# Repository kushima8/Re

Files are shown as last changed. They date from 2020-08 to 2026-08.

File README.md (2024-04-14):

# Re
Split keyboards with rotary encoder<br>

Re40＆Re64

# Build Guide

## Re42_Rev2
End of distribution<br>
[ビルドガイド（日本語）](Re42/Documents/rev2_buildguide_v1.0.md)  
[PCB](https://github.com/kushima8/Re/tree/master/Re42/PCB)
## Re64_Rev2
End of distribution<br>
[ビルドガイド（日本語）](Re64/Documents/rev2_buildguide_v1.0.md)  
[PCB](https://github.com/kushima8/Re/tree/master/Re64/PCB)
## Re93
End of distribution<br>
[ビルドガイド（日本語）](Re93/Documents/buildguide_v1.0.md)  
[PCB](https://github.com/kushima8/Re/tree/master/Re93/PCB)
## Re40
End of distribution<br>
[ビルドガイド（日本語）](Re40/Documents/buildguide_v1.0.md)
## Re42
End of distribution<br>
[ビルドガイド（日本語）](Re42/Documents/buildguide_v1.0.md)
## Re64
End of distribution<br>
[ビルドガイド（日本語）](Re64/Documents/buildguide_v1.0.md)

120px-Cc-by-nc-sa_icon svg

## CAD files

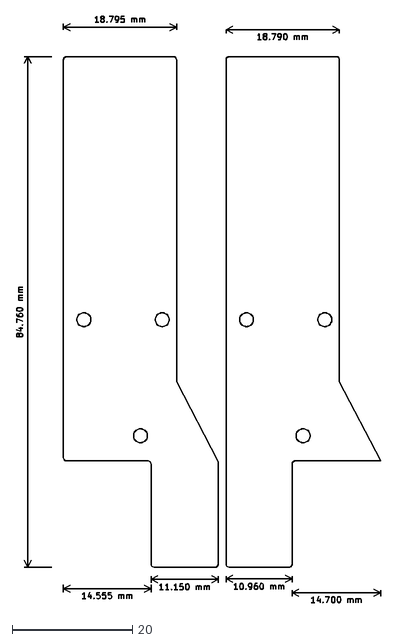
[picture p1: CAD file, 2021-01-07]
Re40/Plate/re40_protective.dxf
60.5 x 97.3

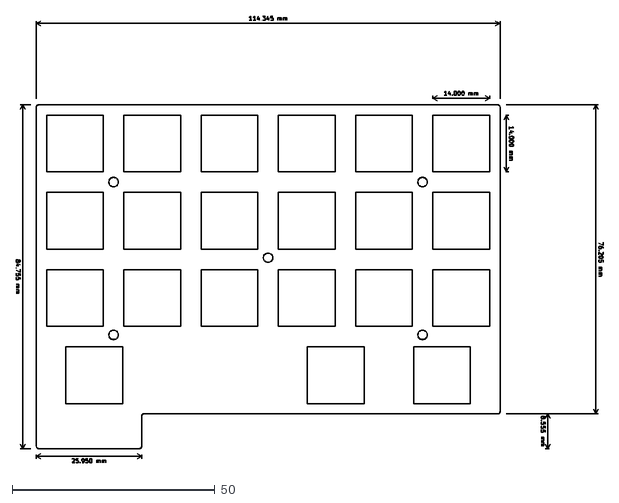
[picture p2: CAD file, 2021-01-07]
Re42/Plate/re42_top.dxf
144.8 x 110.1

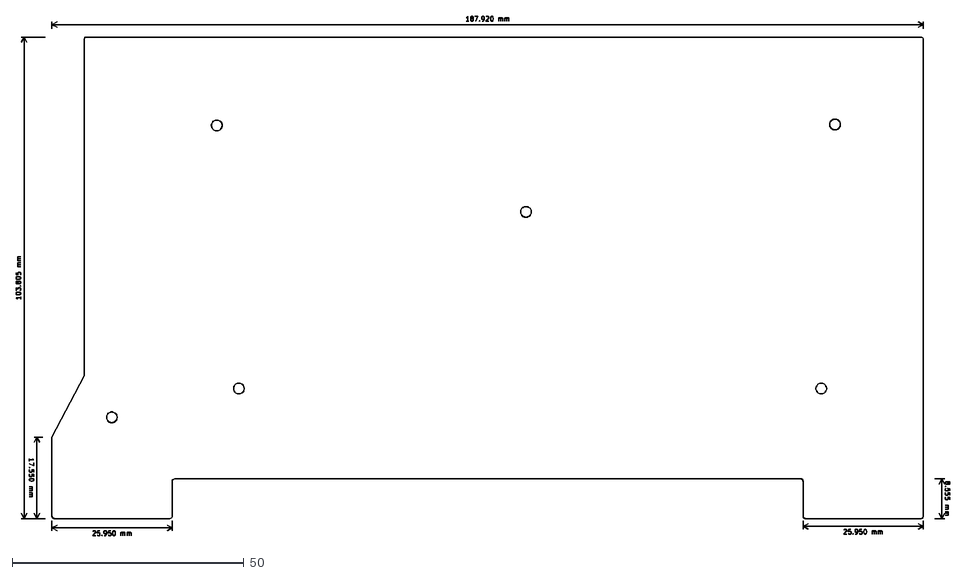
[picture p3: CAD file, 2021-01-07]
Re64/Plate/re64r_bottom.dxf
201.4 x 112.0

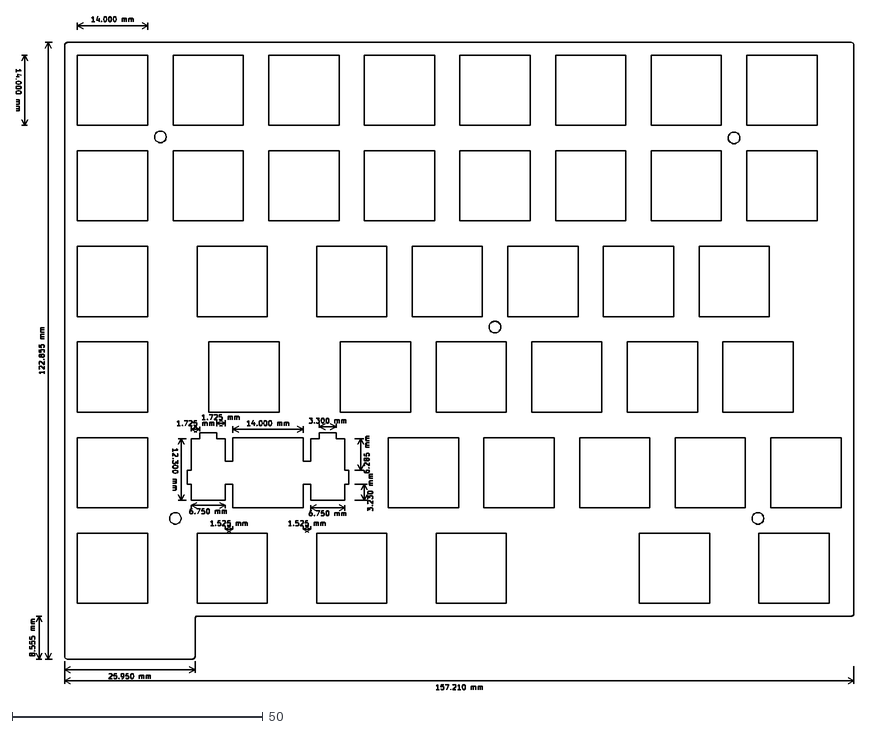
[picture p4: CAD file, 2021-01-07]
Re93/Plate/re93l_top.dxf
166.9 x 134.1

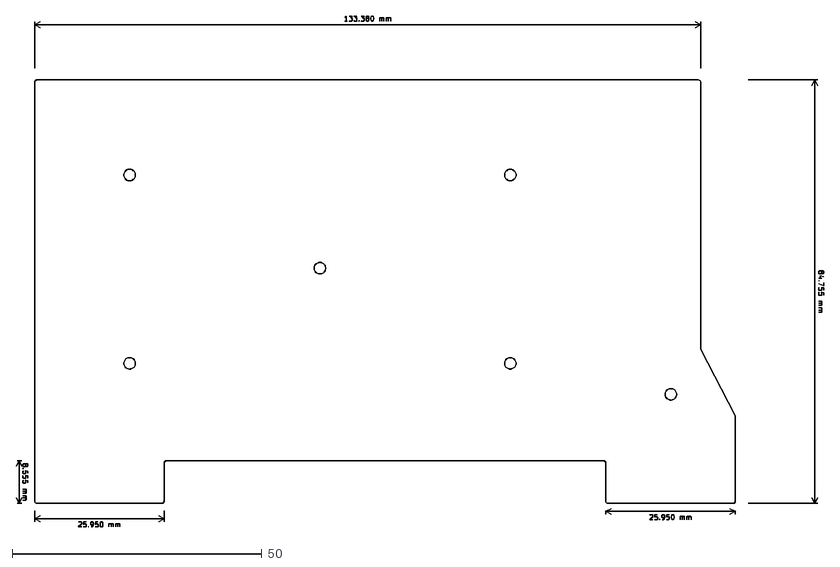
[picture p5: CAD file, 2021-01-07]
Re40/Plate/re40_bottom.dxf
161.7 x 102.3

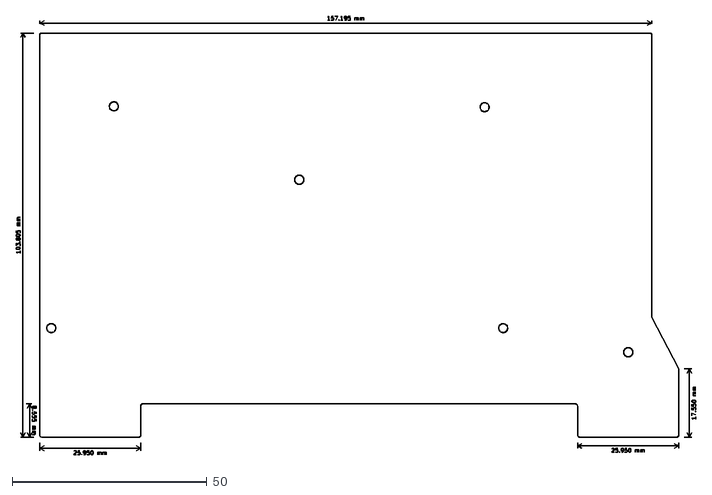
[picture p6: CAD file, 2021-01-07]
Re64/Plate/re64l_bottom.dxf
174.6 x 112.6

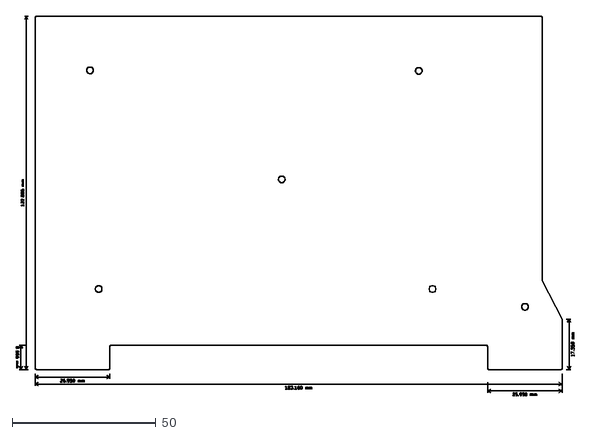
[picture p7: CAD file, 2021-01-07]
Re93/Plate/re93l_bottom.dxf
194.0 x 132.0

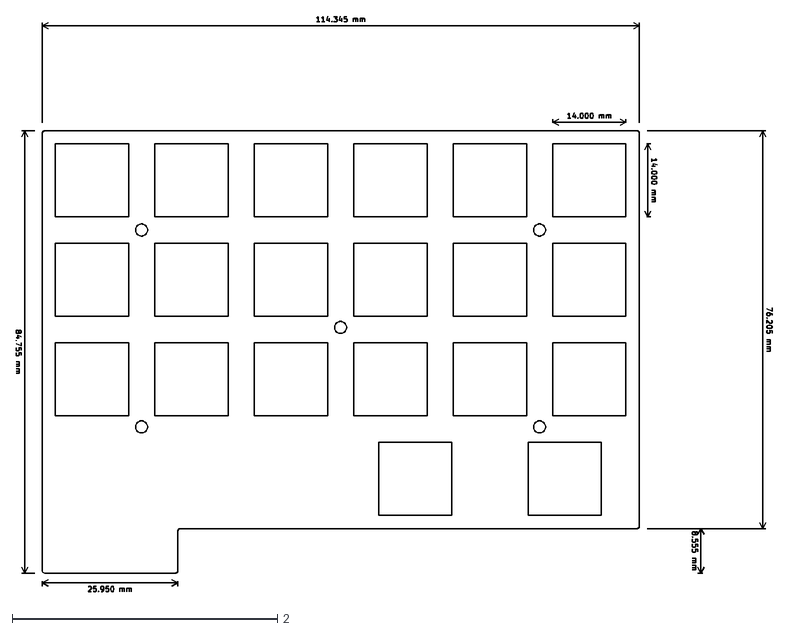
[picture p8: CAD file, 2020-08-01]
Re40/Plate/Re40_top.dxf
5.70 x 4.34

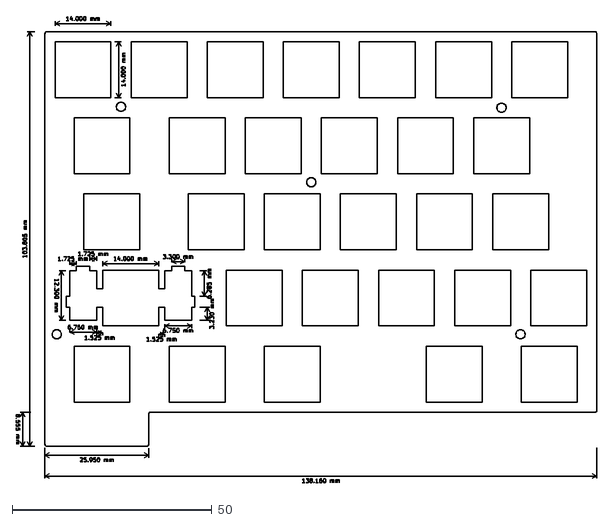
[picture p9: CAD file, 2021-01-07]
Re64/Plate/re64l_top.dxf
145.4 x 116.7

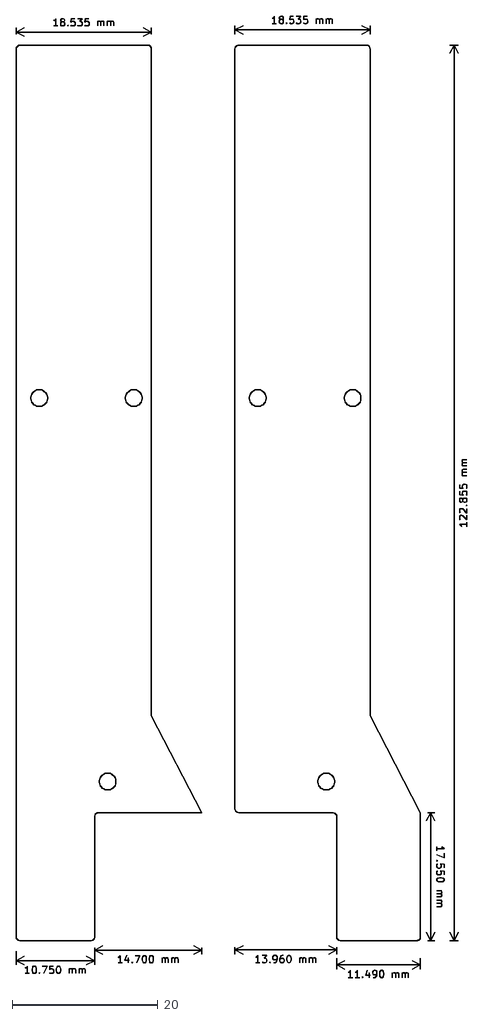
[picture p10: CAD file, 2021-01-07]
Re93/Plate/re93_protective.dxf
61.8 x 131.9

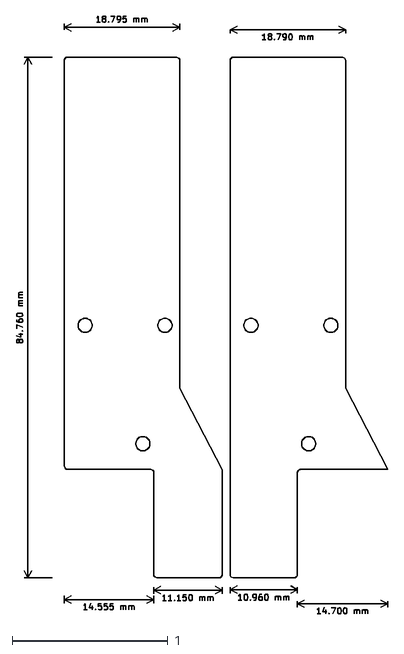
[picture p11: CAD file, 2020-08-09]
Re42/Plate/re42_protective.dxf.dxf
2.38 x 3.83

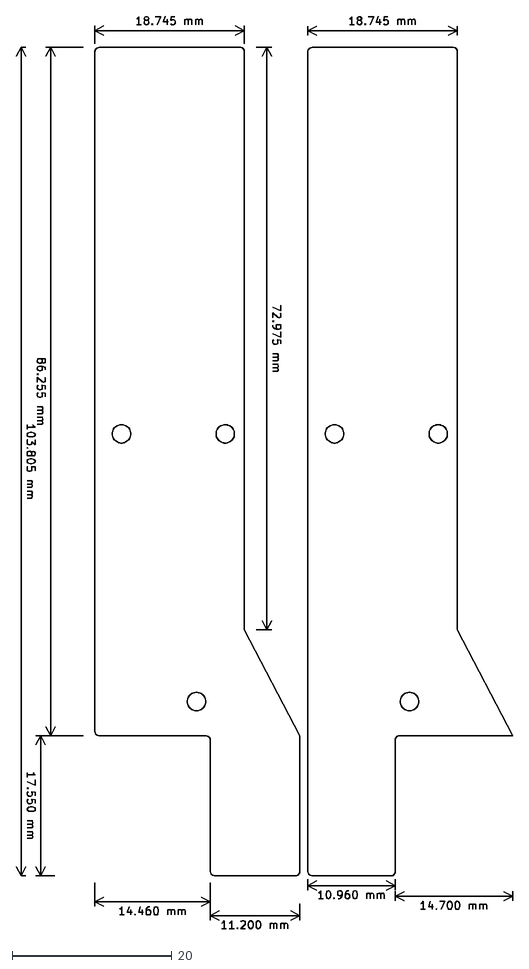
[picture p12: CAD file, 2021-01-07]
Re64/Plate/re64_protective.dxf
62.2 x 114.3

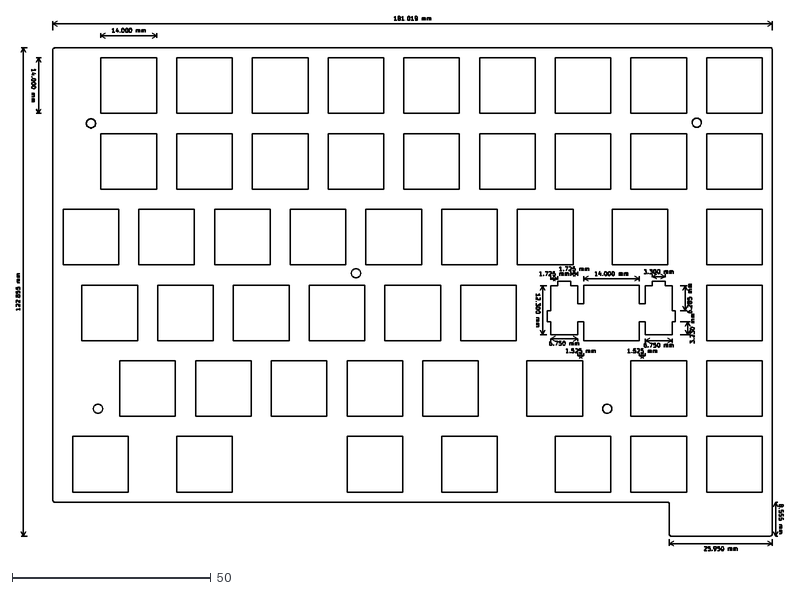
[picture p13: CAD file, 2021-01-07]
Re93/Plate/re93r_top.dxf
193.0 x 134.3

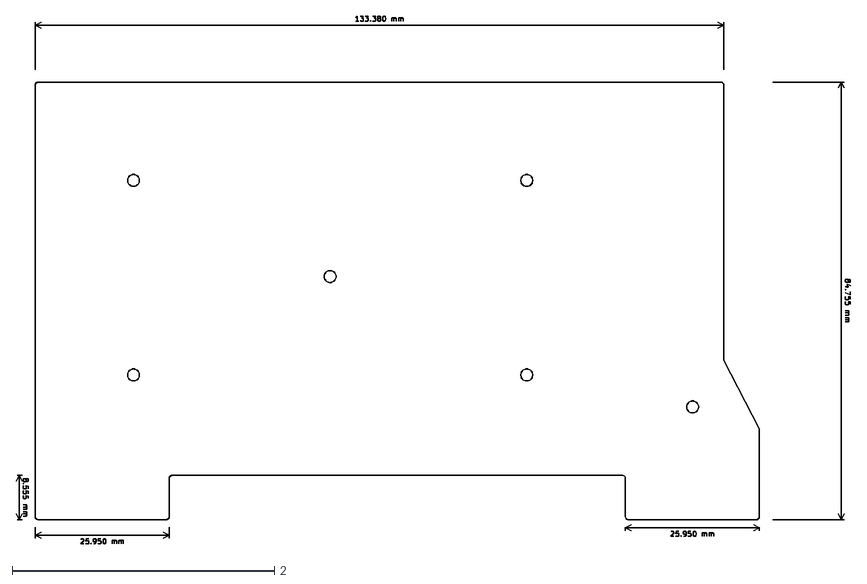
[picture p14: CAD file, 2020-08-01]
Re42/Plate/re42_bottm.dxf
6.37 x 4.03

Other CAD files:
Re64/Plate/re64r_top.dxf
Re93/Plate/re93r_bottom.dxf

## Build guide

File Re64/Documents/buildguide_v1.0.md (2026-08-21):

# Re64_Rev1.0 ビルドガイド

## ご購入前にお読みください

本製品をご購入いただいた時点で、下記「譲渡・再販について」の内容にご同意いただいたものとみなします。

### 譲渡・再販について

BOOTHや遊舎工房など、作者本人が販売または委託している場所以外で購入された場合、同梱品の不足や不良品への対応など、各種サポートをいたしかねます。  
そのため、以下のとおりお願いしております。

1. 本製品（完成品・未完成品・付属部品を問わず）を、ネットオークション、フリマサービス、その他の方法により第三者へ有償で譲渡することを禁止します。
2. 本項に反する行為を確認した場合、以後の販売をお断りする場合があります。

## はじめに
このたびはご購入いただきありがとうございます。  
本製品は組み立てが必要なキットです。  

Re64は親指で操作可能なロータリーエンコーダーを備え、プログラマーなどに人気の高いあの配列を踏襲した60％分割キーボードです。  
使用するキーキャップについては[キーレイアウト](http://www.keyboard-layout-editor.com/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'&_w:2.25%3B&=Enter%3B&@_w:2.25%3B&=Shift&=Z&=X&=C&=V&=B&_x:3.75%3B&=N&=M&=%3C%0A,&=%3E%0A.&=%3F%0A%2F%2F&_w:1.75%3B&=Shift&=Fn%3B&@_w:1.5%3B&=Ctrl&=Fn&_w:1.5%3B&=GUI&_x:0.75&w:1.25%3B&=Space&_w:1.25%3B&=Space&_x:3&w:1.25%3B&=Space&_w:1.5%3B&=Space&_x:0.75&w:1.5%3B&=GUI&=ALT%3B&@_y:-0.75&x:7.25%3B&=SECOND&_x:1%3B&=SECOND)を確認してください。  
※中央付近に突き出した1Uはロータリーエンコーダーのブッシュスイッチを表しています。  

写真は作成見本であり商品内容と同一ではありません。  
また仕様は予告なく変更されることがあります。  

ファームウェアに[qmk_firmware](https://github.com/qmk/qmk_firmware)を採用しています。  
QMKにRe64のコードはまだマージされていませんのでこの[ブランチ](https://github.com/kushima8/qmk_firmware/tree/re)を使用してください。  
動作確認の為にdefaultの[HEXファイル](https://github.com/kushima8/Re/blob/master/Re64/HEX)を用意しています。  
defaultを使用した場合、左側のPro MicroとPCを接続する設定となっております。  
右側で接続した場合はキーマップが反転します。  
反転せずに右側接続を行いたい場合は、右側最上段右端のキーを押下しながら接続することで対応可能です。  

キット作成前にPro Microの書き込み環境の構築を行ってください。  
ファームウェアの書き込み環境の構築については下記のサリチル酸さんのサイトを参考にしてください。  
[（初心者編）自作キーボードにファームウェアを書き込む](https://salicylic-acid3.hatenablog.com/entry/qmk-toolbox)  

キー割り当ての変更方法などはご自身でお調べいただくようお願いします。  

GUIから簡単にキー割り当てを変更できる[VIA](https://caniusevia.com/)と[Remap](https://remap-keys.app/)に対応しております。  
ロータリーエンコーダの回転割り当ても含め、設定できますのでご活用ください。  
VIAとRemapについては下記のサリチル酸さんのサイトを参考にしてください。  
[（初心者編）VIAを使ってキーマップを書き換えよう](https://salicylic-acid3.hatenablog.com/entry/via-manual)  
[（初心者編）Remapを使ってキーマップを書き換えよう](https://salicylic-acid3.hatenablog.com/entry/remap-manual)  
OLEDを接続していない場合は[re64_via.hex](https://github.com/kushima8/Re/blob/master/Re64/VIA/re64_via.hex)を、  
接続している場合は[re64_via_oled.hex](https://github.com/kushima8/Re/blob/master/Re64/VIA/re64_via_oled.hex)を使用してください。  
[re64_via.hex](https://github.com/kushima8/Re/blob/master/Re64/VIA/re64_via.hex)と[re64_via_oled.hex](https://github.com/kushima8/Re/blob/master/Re64/VIA/re64_via_oled.hex)ではロータリーエンコーダの初期割り当てが未設定ですので、動作確認時には[Remap](https://remap-keys.app/)などで割り当て設定をしてください。  

[プレートのデータ](https://github.com/kushima8/Re/tree/master/Re64/Plate)は公開中です。  
アルミプレートなど作成したい場合にお使いください。  

Type-C端子搭載のiPadと接続可能です。  
iPad mini 6にて簡易動作確認済みです。  
一部iPadでは対応していないキーコードがありますのでご注意ください。  

以下の部品リストを参考に欠品がないか確認をお願いします。  

## 部品

### キットに付属しているもの

|名称|数量|備考|
|----|:---:|----|
|PCB|2枚|右側用、左側用各1枚ずつ|
|トッププレート|2枚|右側用、左側用各1枚ずつ|
|ボトムプレート|2枚|右側用、左側用各1枚ずつ|
|保護プレート|4枚|内側用、外側用各2枚ずつ|
|M2 3mmスペーサー(ARB-2003E)|10個|丸型両メネジ|
|M2 6mmスペーサー(ARB-2006E)|12個|丸型両メネジ|
|M2 8mmスペーサー(ARB-2008E)|6個|丸型両メネジ|
|M2 4mmネジ|20本|
|M2 8mmネジ|10本|
|M2 12mmネジ|2本|
|ダイオード(1N4148)|66本|若干多めの場合あり|
|Kailh PCB ソケット(MX用)|64個|
|タクトスイッチ|2個|
|TRRSジャック(MJ-4PP-9)|2個|
|プッシュスイッチ内蔵ロータリーエンコーダ(PEC12R-4222F-S0024)|2個|
|ゴム足|8個|

### 別途、購入が必ず必要なもの
以下の部品は別途購入してください。

|名称|数量|備考|
|----|:---:|----|
|キースイッチ(Cherry MX互換)|64個|
|キーキャップ(Cherry MX互換)|64個|
|Pro Micro|2個|
|コンスルーピンヘッダ	|4個|
|ロータリーエンコーダー用つまみ|2個|
|TRRSケーブル|1本|
|2Uスタビライザー(Cherry MX互換)|2個|

### オプション
以下の部品はオプション品です。
キーボードを光らせたいなどの場合のみ別途購入してください。

|名称|数量|備考|
|----|:---:|----|
|LEDチップ(YS-SK6812MINI-E)|64個|
|OLEDモジュール|2個|
|OLED用ピンソケット|2個|

## 組み立て
* Daihukuさんによるビルドログ動画があります。  
  本機を作成するにあたって参考になると思いますので是非御覧ください。  
 https://www.youtube.com/watch?v=lg03LpNXRAI
* 表面  
  
* 裏面  
  
* 1.Pro Microのはんだ付け
  * チップが載っている面が内側になるようにし、コンスルーピンヘッダを取り付けはんだ付けをしてください。
  * コンスルーピンヘッダには取り付け方向があるため気をつけてください。
  * [コンスルー - Self-Made Keyboards in Japan - ](https://scrapbox.io/self-made-kbds-ja/%E3%82%B3%E3%83%B3%E3%82%B9%E3%83%AB%E3%83%BC)  
  
* 2.ファームウェアの書き込み
  * [re64_default.hex](https://github.com/kushima8/Re/blob/master/Re64/HEX/re64_default.hex)を指定してファームウェアを書き込んでください。
  * OLEDを使用する場合は'rules.mk'内の'OLED_DRIVER_ENABLE'を'yes'に書き換え、ご自身で環境を作っていただきファームウェアをコンパイルして頂くか、
  * もしくは[re64_via_oled.hex](https://github.com/kushima8/Re/blob/master/Re64/VIA/re64_via_oled.hex)を指定してファームウェアを書き込んでください。
  * [re64_via_oled.hex](https://github.com/kushima8/Re/blob/master/Re64/VIA/re64_via_oled.hex)ではロータリーエンコーダの初期割り当てが未設定ですので、動作確認時には[Remap](https://remap-keys.app/)などで割り当て設定をしてください。
* 3.LEDチップのはんだ付け(オプション)
  * LEDチップ((YS-SK6812MINI-E)はPCBを裏面にして右上から左下、反転したZ字を書くように実装してください。
  * 高い温度ではんだ付けを行うとLED破損の可能性がありますので、約270℃に設定してはんだ付けをするようにしてください。
  * LEDは足が欠けている箇所が左下に来るように設置し、はんだ付けを行ってください。
  * はんだ付けが完了したら一度Pro Microを取り付け、LEDが光るかどうかテストを行ってください。  
  
* 4.ダイオードのはんだ付け
  * ダイオードの足を曲げ、PCB前面から取り付け、裏面からはんだ付けを行ってください。
  * ダイオードの向きは前面から見て左(三角形の頂点の先に縦棒がある方)に黒帯が来るように設置しはんだ付けを行ってください。
* 5.Kailh PCB ソケット
  * 中央の穴に干渉しないようにソケットを設置してください。
  * ソケットの片側はんだ付けをしっかりと行い、基盤から浮いていないようであればもう片方もはんだ付けをしっかりと行ってください。
* 6.タクトスイッチ、TRRSジャックのはんだ付け
  * PCB表面から取り付け、裏面からはんだ付けを行ってください。
* 7.OLEDモジュール、OLED用ピンソケットのはんだ付け(オプション)
  * OLEDモジュールとピンヘッダのハンダ付けを行ってください。
  * ピンソケットをPCB表面から取り付け、裏面からはんだ付けを行ってください。
* 8.ロータリーエンコーダのはんだ付け
  * ロータリーエンコーダーの取り付け位置は内側と外側の選択式となっております。
  * どちらを選択しても同じ動作をするように設計しています。
  
  * 使用するつまみ、または自身の手の大きさなどを考慮し自身で内側か外側かの選択を行ってください。
  * 取り付け位置選択後、PCB表面からロータリーエンコーダを取り付け、裏面からはんだ付けを行ってください。
* 9.スタビライザーの取り付け
  * 基盤にスタビライザーを取り付けてください。
* 10.トッププレートの取り付け
  * トッププレートの保護フィルムを剥がし、M2 3mmスペーサーをM2 8mmネジで固定してください。
  * その後、PCB表面に取り付け、サンドするようにM2 6mmスペーサーを裏面から取り付けてください。
* 11.保護プレート用スペーサーの取り付け
  * Pro Micro取り付け位置直下に位置する2箇所の穴に裏面からM2 4mmネジを入れ、M2 8mmスペーサーで固定してください。
* 12.ボトムプレートの取り付け
  * ボトムプレートの保護フィルムを剥がし、基板上でロータリーエンコーダの上部に位置する穴に対して裏面からM2 12mmネジを入れ、M2 6mmスペーサーで固定してください。
  * その後、M2 4mmネジを仕様し残りの箇所を固定してください。
* 13.キースイッチの取り付け
  * 基盤にキースイッチを取り付けてください。
* 14.Pro Microの取り付け
  * Pro Microを取り付け、PCと接続し、キースイッチとロータリーエンコーダの入力の確認を行ってください。
* 15.OLEDモジュールの取り付け(オプション)
  * OLEDモジュールを取り付け、PCと接続し、表示されることの確認を行ってください。
  * デフォルトでは左側にはレイヤーとLEDの光度情報、右側は真っ白な長方形が表示されます。
* 16.保護プレートの取り付け
  * ロータリーエンコーダーを内側に取り付けた場合は外側用の、内側に取り付けた場合は外側用の保護プレートを使用します。
  * ロータリーエンコーダー上部に位置する箇所から飛び出ているネジにM2 8mmスペーサーを固定。
  * そして、保護フィルムを剥がし、表面からM2 4mmねじで保護プレートを固定してください。
* 17.つまみの取り付け
  * つまみをロータリーエンコーダーに取り付けてください。
* 18.キーキャップの取り付け
  * キースイッチにキーキャップを取り付けてください。
  * 使用するキーキャップについては[キーレイアウト](http://www.keyboard-layout-editor.com/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'&_w:2.25%3B&=Enter%3B&@_w:2.25%3B&=Shift&=Z&=X&=C&=V&=B&_x:3.75%3B&=N&=M&=%3C%0A,&=%3E%0A.&=%3F%0A%2F%2F&_w:1.75%3B&=Shift&=Fn%3B&@_w:1.5%3B&=Ctrl&=Fn&_w:1.5%3B&=GUI&_x:0.75&w:1.25%3B&=Space&_w:1.25%3B&=Space&_x:3&w:1.25%3B&=Space&_w:1.5%3B&=Space&_x:0.75&w:1.5%3B&=GUI&=ALT%3B&@_y:-0.75&x:7.25%3B&=SECOND&_x:1%3B&=SECOND)を確認してください。
* 19.ゴム足の取り付け
  * ボトムプレートにゴム足を取り付けください。

組み立ての手順は、以上です。

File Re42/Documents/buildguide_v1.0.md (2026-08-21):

# Re42_Rev1.0 ビルドガイド

## ご購入前にお読みください

本製品をご購入いただいた時点で、下記「譲渡・再販について」の内容にご同意いただいたものとみなします。

### 譲渡・再販について

BOOTHや遊舎工房など、作者本人が販売または委託している場所以外で購入された場合、同梱品の不足や不良品への対応など、各種サポートをいたしかねます。  
そのため、以下のとおりお願いしております。

1. 本製品（完成品・未完成品・付属部品を問わず）を、ネットオークション、フリマサービス、その他の方法により第三者へ有償で譲渡することを禁止します。
2. 本項に反する行為を確認した場合、以後の販売をお断りする場合があります。

## はじめに
このたびはご購入いただきありがとうございます。  
本製品は組み立てが必要なキットです。  

Re42は親指で操作可能なロータリーエンコーダーを備える40％分割キーボードです。  
使用するキーキャップについては[キーレイアウト](http://www.keyboard-layout-editor.com/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'%3B&@=Shift&=Z&=X&=C&=V&=B&_x:3.25%3B&=N&=M&=%3C%0A,&=%3E%0A.&=%3F%0A%2F%2F&=Shift%3B&@_a:7&w:1.5%3B&=&_x:1.75&a:4&w:1.5%3B&=RAISE&_w:1.25%3B&=Space&_x:3.25&w:1.25%3B&=Enter&_w:1.5%3B&=LOWER&_x:1.75&a:7&w:1.5%3B&=%3B&@_y:-0.75&x:6&a:4%3B&=TENKEY&_x:1.25%3B&=SECOND)を確認してください。  
※中央付近に突き出した1Uはロータリーエンコーダーのブッシュスイッチを表しています。  

写真は作成見本であり商品内容と同一ではありません。  
また仕様は予告なく変更されることがあります。  

ファームウェアに[qmk_firmware](https://github.com/qmk/qmk_firmware)を採用しています。  
QMKにRe42のコードはまだマージされていませんのでこの[ブランチ](https://github.com/kushima8/qmk_firmware/tree/re)を使用してください。  
動作確認の為にdefaultの[HEXファイル](https://github.com/kushima8/Re/blob/master/Re42/HEX)を用意しています。  
defaultを使用した場合、左側右側どちらのPro MicroでもPCを接続可能な設定となっております。  

キット作成前にPro Microの書き込み環境の構築を行ってください。  
ファームウェアの書き込み環境の構築については下記のサリチル酸さんのサイトを参考にしてください。  
[（初心者編）自作キーボードにファームウェアを書き込む](https://salicylic-acid3.hatenablog.com/entry/qmk-toolbox)  

キー割り当ての変更方法などはご自身でお調べいただくようお願いします。  

GUIから簡単にキー割り当てを変更できる[VIA](https://caniusevia.com/)と[Remap](https://remap-keys.app/)に対応しております。  
ロータリーエンコーダの回転割り当ても含め、設定できますのでご活用ください。  
VIAとRemapについては下記のサリチル酸さんのサイトを参考にしてください。  
[（初心者編）VIAを使ってキーマップを書き換えよう](https://salicylic-acid3.hatenablog.com/entry/via-manual)  
[（初心者編）Remapを使ってキーマップを書き換えよう](https://salicylic-acid3.hatenablog.com/entry/remap-manual)  
OLEDを接続していない場合は[re42_via.hex](https://github.com/kushima8/Re/blob/master/Re42/VIA/re42_via.hex)を、  
接続している場合は[re42_via_oled.hex](https://github.com/kushima8/Re/blob/master/Re42/VIA/re42_via_oled.hex)を使用してください。  
[re42_via.hex](https://github.com/kushima8/Re/blob/master/Re42/VIA/re42_via.hex)と[re42_via_oled.hex](https://github.com/kushima8/Re/blob/master/Re42/VIA/re42_via_oled.hex)ではロータリーエンコーダの初期割り当てが未設定ですので、動作確認時には[Remap](https://remap-keys.app/)などで割り当て設定をしてください。  

[プレートのデータ](https://github.com/kushima8/Re/tree/master/Re42/Plate)は公開中です。  
アルミプレートなど作成したい場合にお使いください。  

Type-C端子搭載のiPadと接続可能です。  
iPad mini 6にて簡易動作確認済みです。  
一部iPadでは対応していないキーコードがありますのでご注意ください。  

以下の部品リストを参考に欠品がないか確認をお願いします。  

## 部品

### キットに付属しているもの

|名称|数量|備考|
|----|:---:|----|
|PCB|2枚|右側用、左側用各1枚ずつ|
|トッププレート|2枚|右側用、左側用各1枚ずつ|
|ボトムプレート|2枚|右側用、左側用各1枚ずつ|
|保護プレート|4枚|内側用、外側用各2枚ずつ|
|M2 3mmスペーサー(ARB-2003E)|10個|丸型両メネジ|
|M2 6mmスペーサー(ARB-2006E)|12個|丸型両メネジ|
|M2 8mmスペーサー(ARB-2008E)|6個|丸型両メネジ|
|M2 4mmネジ|20本|
|M2 8mmネジ|10本|
|M2 12mmネジ|2本|
|ダイオード(1N4148)|44本|若干多めの場合あり|
|Kailh PCB ソケット(MX用)|42個|
|タクトスイッチ|2個|
|TRRSジャック(MJ-4PP-9)|2個|
|プッシュスイッチ内蔵ロータリーエンコーダ(PEC12R-4222F-S0024)|2個|
|ゴム足|8個|

### 別途、購入が必ず必要なもの
以下の部品は別途購入してください。

|名称|数量|備考|
|----|:---:|----|
|キースイッチ(Cherry MX互換)|42個|
|キーキャップ(Cherry MX互換)|42個|
|Pro Micro|2個|
|コンスルーピンヘッダ	|4個|
|ロータリーエンコーダー用つまみ|2個|
|TRRSケーブル|1本|

### オプション
以下の部品はオプション品です。
キーボードを光らせたいなどの場合のみ別途購入してください。

|名称|数量|備考|
|----|:---:|----|
|LEDチップ(YS-SK6812MINI-E)|42個|
|OLEDモジュール|2個|
|OLED用ピンソケット|2個|

## 組み立て
* Re64(Rev1)になりますが、Daihukuさんによるビルドログ動画があります。
  作成手順が似ており、本機を作成するにあたって参考になると思いますので是非御覧ください。
　https://www.youtube.com/watch?v=lg03LpNXRAI
* 表面  
    ![001]()
* 裏面  
    ![002]()
* 1.Pro Microのはんだ付け
  * チップが載っている面が内側になるようにし、コンスルーピンヘッダを取り付けはんだ付けをしてください。
  * コンスルーピンヘッダには取り付け方向があるため気をつけてください。
  * [コンスルー - Self-Made Keyboards in Japan - ](https://scrapbox.io/self-made-kbds-ja/%E3%82%B3%E3%83%B3%E3%82%B9%E3%83%AB%E3%83%BC)  
  
* 2.ファームウェアの書き込み
  * [Re42_default.hex](https://github.com/kushima8/Re/blob/master/Re42/HEX/Re42_default.hex)を指定してファームウェアを書き込んでください。
  * OLEDを使用する場合は'rules.mk'内の'OLED_DRIVER_ENABLE'を'yes'に書き換え、ご自身で環境を作っていただきファームウェアをコンパイルして頂くか、
  * もしくは[Re42_via_oled.hex](https://github.com/kushima8/Re/blob/master/Re42/VIA/Re42_via_oled.hex)を指定してファームウェアを書き込んでください。
  * [re42_via_oled.hex](https://github.com/kushima8/Re/blob/master/Re40/VIA/re40_via_oled.hex)ではロータリーエンコーダの初期割り当てが未設定ですので、動作確認時には[Remap](https://remap-keys.app/)などで割り当て設定をしてください。
* 3.LEDチップのはんだ付け(オプション)
  * LEDチップ((YS-SK6812MINI-E)はPCBを裏面にして右上から左下、反転したZ字を書くように実装してください。
  * 高い温度ではんだ付けを行うとLED破損の可能性がありますので、約270℃に設定してはんだ付けをするようにしてください。
  * LEDは足が欠けている箇所が左下に来るように設置し、はんだ付けを行ってください。
  * はんだ付けが完了したら一度Pro Microを取り付け、LEDが光るかどうかテストを行ってください。  
  
* 4.ダイオードのはんだ付け
  * ダイオードの足を曲げ、PCB前面から取り付け、裏面からはんだ付けを行ってください。
  * ダイオードの向きは前面から見て左(三角形の頂点の先に縦棒がある方)に黒帯が来るように設置しはんだ付けを行ってください。
* 5.Kailh PCB ソケット
  * 中央の穴に干渉しないようにソケットを設置してください。
  * ソケットの片側はんだ付けをしっかりと行い、基盤から浮いていないようであればもう片方もはんだ付けをしっかりと行ってください。
* 6.タクトスイッチ、TRRSジャックのはんだ付け
  * PCB表面から取り付け、裏面からはんだ付けを行ってください。
* 7.OLEDモジュール、OLED用ピンソケットのはんだ付け(オプション)
  * OLEDモジュールとピンヘッダのハンダ付けを行ってください。
  * ピンソケットをPCB表面から取り付け、裏面からはんだ付けを行ってください。
* 8.ロータリーエンコーダのはんだ付け
  * ロータリーエンコーダーの取り付け位置は内側と外側の選択式となっております。
  * どちらを選択しても同じ動作をするように設計しています。
  
  * 使用するつまみ、または自身の手の大きさなどを考慮し自身で内側か外側かの選択を行ってください。
  * 取り付け位置選択後、PCB表面からロータリーエンコーダを取り付け、裏面からはんだ付けを行ってください。
* 9.トッププレートの取り付け
  * トッププレートの保護フィルムを剥がし、M2 3mmスペーサーをM2 8mmネジで固定してください。
  * その後、PCB表面に取り付け、サンドするようにM2 6mmスペーサーを裏面から取り付けてください。
* 10.保護プレート用スペーサーの取り付け
  * Pro Micro取り付け位置直下に位置する2箇所の穴に裏面からM2 4mmネジを入れ、M2 8mmスペーサーで固定してください。
* 11.ボトムプレートの取り付け
  * ボトムプレートの保護フィルムを剥がし、基板上でロータリーエンコーダの上部に位置する穴に対して裏面からM2 12mmネジを入れ、M2 6mmスペーサーで固定してください。
  * その後、M2 4mmネジ使用し残りの箇所を固定してください。
* 12.キースイッチの取り付け
  * 基盤にキースイッチを取り付けてください。
* 13.Pro Microの取り付け
  * Pro Microを取り付け、PCと接続し、キースイッチとロータリーエンコーダの入力の確認を行ってください。
* 14.OLEDモジュールの取り付け(オプション)
  * OLEDモジュールを取り付け、PCと接続し、表示されることの確認を行ってください。
  * デフォルトでは左側にはレイヤーとLEDの光度情報、右側は真っ白な長方形が表示されます。
* 15.保護プレートの取り付け
  * ロータリーエンコーダーを内側に取り付けた場合は外側用の、内側に取り付けた場合は外側用の保護プレートを使用します。
  * ロータリーエンコーダー上部に位置する箇所から飛び出ているネジにM2 8mmスペーサーを固定。
  * そして、保護フィルムを剥がし、表面からM2 4mmねじで保護プレートを固定してください。
* 16.つまみの取り付け
  * つまみをロータリーエンコーダーに取り付けてください。
* 17.キーキャップの取り付け
  * キースイッチにキーキャップを取り付けてください。
  * 使用するキーキャップについては[キーレイアウト](http://www.keyboard-layout-editor.com/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'%3B&@=Shift&=Z&=X&=C&=V&=B&_x:3.25%3B&=N&=M&=%3C%0A,&=%3E%0A.&=%3F%0A%2F%2F&=Shift%3B&@_a:7&w:1.5%3B&=&_x:1.75&a:4&w:1.5%3B&=RAISE&_w:1.25%3B&=Space&_x:3.25&w:1.25%3B&=Enter&_w:1.5%3B&=LOWER&_x:1.75&a:7&w:1.5%3B&=%3B&@_y:-0.75&x:6&a:4%3B&=TENKEY&_x:1.25%3B&=SECOND)を確認してください。
* 18.ゴム足の取り付け
  * ボトムプレートにゴム足を取り付けください。

組み立ての手順は、以上です。

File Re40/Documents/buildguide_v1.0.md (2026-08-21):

# Re40_Rev1.0 ビルドガイド

## ご購入前にお読みください

本製品をご購入いただいた時点で、下記「譲渡・再販について」の内容にご同意いただいたものとみなします。

### 譲渡・再販について

BOOTHや遊舎工房など、作者本人が販売または委託している場所以外で購入された場合、同梱品の不足や不良品への対応など、各種サポートをいたしかねます。  
そのため、以下のとおりお願いしております。

1. 本製品（完成品・未完成品・付属部品を問わず）を、ネットオークション、フリマサービス、その他の方法により第三者へ有償で譲渡することを禁止します。
2. 本項に反する行為を確認した場合、以後の販売をお断りする場合があります。

## はじめに
このたびはご購入いただきありがとうございます。  
本製品は組み立てが必要なキットです。  

Re40は親指で操作可能なロータリーエンコーダーを備える40％分割キーボードです。  
使用するキーキャップについては[キーレイアウト](http://www.keyboard-layout-editor.com/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'%3B&@=Shift&=Z&=X&=C&=V&=B&_x:3.25%3B&=N&=M&=%3C%0A,&=%3E%0A.&=%3F%0A%2F%2F&=Shift%3B&@_x:3&w:1.5%3B&=RAISE&_w:1.5%3B&=Space&_x:3.25&w:1.5%3B&=Enter&_w:1.5%3B&=LOWER%3B&@_y:-0.75&x:6%3B&=TENKEY&_x:1.25%3B&=SECOND)を確認してください。  
※中央付近に突き出した1Uはロータリーエンコーダーのブッシュスイッチを表しています。  

写真は作成見本であり商品内容と同一ではありません。  
また仕様は予告なく変更されることがあります。  

ファームウェアに[qmk_firmware](https://github.com/qmk/qmk_firmware)を採用しています。  
QMKにRe40のコードはまだマージされていませんのでこの[ブランチ](https://github.com/kushima8/qmk_firmware/tree/re)を使用してください。  
動作確認の為にdefaultの[HEXファイル](https://github.com/kushima8/Re/blob/master/Re40/HEX)を用意しています。  
defaultを使用した場合、左側のPro MicroとPCを接続する設定となっております。  
右側で接続した場合はキーマップが反転します。  
反転せずに右側接続を行いたい場合は、右側最上段右端のキーを押下しながら接続することで対応可能です。  

キット作成前にPro Microの書き込み環境の構築を行ってください。  
ファームウェアの書き込み環境の構築については下記のサリチル酸さんのサイトを参考にしてください。  
[（初心者編）自作キーボードにファームウェアを書き込む](https://salicylic-acid3.hatenablog.com/entry/qmk-toolbox)  

キー割り当ての変更方法などはご自身でお調べいただくようお願いします。  

GUIから簡単にキー割り当てを変更できる[VIA](https://caniusevia.com/)と[Remap](https://remap-keys.app/)に対応しております。  
ロータリーエンコーダの回転割り当ても含め、設定できますのでご活用ください。  
VIAとRemapについては下記のサリチル酸さんのサイトを参考にしてください。  
[（初心者編）VIAを使ってキーマップを書き換えよう](https://salicylic-acid3.hatenablog.com/entry/via-manual)  
[（初心者編）Remapを使ってキーマップを書き換えよう](https://salicylic-acid3.hatenablog.com/entry/remap-manual)  
OLEDを接続していない場合は[re40_via.hex](https://github.com/kushima8/Re/blob/master/Re40/VIA/re40_via.hex)を、  
接続している場合は[re40_via_oled.hex](https://github.com/kushima8/Re/blob/master/Re40/VIA/re40_via_oled.hex)を使用してください。  
[re40_via.hex](https://github.com/kushima8/Re/blob/master/Re40/VIA/re40_via.hex)と[re40_via_oled.hex](https://github.com/kushima8/Re/blob/master/Re40/VIA/re40_via_oled.hex)ではロータリーエンコーダの初期割り当てが未設定ですので、動作確認時には[Remap](https://remap-keys.app/)などで割り当て設定をしてください。  

[プレートのデータ](https://github.com/kushima8/Re/tree/master/Re40/Plate)は公開中です。  
アルミプレートなど作成したい場合にお使いください。  

Type-C端子搭載のiPadと接続可能です。  
iPad mini 6にて簡易動作確認済みです。  
一部iPadでは対応していないキーコードがありますのでご注意ください。  

以下の部品リストを参考に欠品がないか確認をお願いします。  

## 部品

### キットに付属しているもの

|名称|数量|備考|
|----|:---:|----|
|PCB|2枚|右側用、左側用各1枚ずつ|
|トッププレート|2枚|右側用、左側用各1枚ずつ|
|ボトムプレート|2枚|右側用、左側用各1枚ずつ|
|保護プレート|4枚|内側用、外側用各2枚ずつ|
|M2 3mmスペーサー(ARB-2003E)|10個|丸型両メネジ|
|M2 6mmスペーサー(ARB-2006E)|12個|丸型両メネジ|
|M2 8mmスペーサー(ARB-2008E)|6個|丸型両メネジ|
|M2 4mmネジ|20本|
|M2 8mmネジ|10本|
|M2 12mmネジ|2本|
|ダイオード(1N4148)|42本|若干多めの場合あり|
|Kailh PCB ソケット(MX用)|40個|
|タクトスイッチ|2個|
|TRRSジャック(MJ-4PP-9)|2個|
|プッシュスイッチ内蔵ロータリーエンコーダ(PEC12R-4222F-S0024)|2個|
|ゴム足|8個|

### 別途、購入が必ず必要なもの
以下の部品は別途購入してください。

|名称|数量|備考|
|----|:---:|----|
|キースイッチ(Cherry MX互換)|40個|
|キーキャップ(Cherry MX互換)|40個|
|Pro Micro|2個|
|コンスルーピンヘッダ	|4個|
|ロータリーエンコーダー用つまみ|2個|
|TRRSケーブル|1本|

### オプション
以下の部品はオプション品です。
キーボードを光らせたいなどの場合のみ別途購入してください。

|名称|数量|備考|
|----|:---:|----|
|LEDチップ(YS-SK6812MINI-E)|40個|
|OLEDモジュール|2個|
|OLED用ピンソケット|2個|

## 組み立て
* Re64(Rev1)になりますが、Daihukuさんによるビルドログ動画があります。  
 作成手順が似ており、本機を作成するにあたって参考になると思いますので是非御覧ください。  
 https://www.youtube.com/watch?v=lg03LpNXRAI
* 表面  
  
* 裏面  
  
* 1.Pro Microのはんだ付け
  * チップが載っている面が内側になるようにし、コンスルーピンヘッダを取り付けはんだ付けをしてください。
  * コンスルーピンヘッダには取り付け方向があるため気をつけてください。
  * [コンスルー - Self-Made Keyboards in Japan - ](https://scrapbox.io/self-made-kbds-ja/%E3%82%B3%E3%83%B3%E3%82%B9%E3%83%AB%E3%83%BC)  
  
* 2.ファームウェアの書き込み
  * [re40_default.hex](https://github.com/kushima8/Re/blob/master/Re40/HEX/re40_default.hex)を指定してファームウェアを書き込んでください。
  * OLEDを使用する場合は'rules.mk'内の'OLED_DRIVER_ENABLE'を'yes'に書き換え、ご自身で環境を作っていただきファームウェアをコンパイルして頂くか、
  * もしくは[re40_via_oled.hex](https://github.com/kushima8/Re/blob/master/Re40/VIA/re40_via_oled.hex)を指定してファームウェアを書き込んでください。
  * [re40_via_oled.hex](https://github.com/kushima8/Re/blob/master/Re40/VIA/re40_via_oled.hex)ではロータリーエンコーダの初期割り当てが未設定ですので、動作確認時には[Remap](https://remap-keys.app/)などで割り当て設定をしてください。
* 3.LEDチップのはんだ付け(オプション)
  * LEDチップ((YS-SK6812MINI-E)はPCBを裏面にして右上から左下、反転したZ字を書くように実装してください。
  * 高い温度ではんだ付けを行うとLED破損の可能性がありますので、約270℃に設定してはんだ付けをするようにしてください。
  * LEDは足が欠けている箇所が左下に来るように設置し、はんだ付けを行ってください。
  * はんだ付けが完了したら一度Pro Microを取り付け、LEDが光るかどうかテストを行ってください。  
  
* 4.ダイオードのはんだ付け
  * ダイオードの足を曲げ、PCB前面から取り付け、裏面からはんだ付けを行ってください。
  * ダイオードの向きは前面から見て左(三角形の頂点の先に縦棒がある方)に黒帯が来るように設置しはんだ付けを行ってください。
* 5.Kailh PCB ソケット
  * 中央の穴に干渉しないようにソケットを設置してください。
  * ソケットの片側はんだ付けをしっかりと行い、基盤から浮いていないようであればもう片方もはんだ付けをしっかりと行ってください。
* 6.タクトスイッチ、TRRSジャックのはんだ付け
  * PCB表面から取り付け、裏面からはんだ付けを行ってください。
* 7.OLEDモジュール、OLED用ピンソケットのはんだ付け(オプション)
  * OLEDモジュールとピンヘッダのハンダ付けを行ってください。
  * ピンソケットをPCB表面から取り付け、裏面からはんだ付けを行ってください。
* 8.ロータリーエンコーダのはんだ付け
  * ロータリーエンコーダーの取り付け位置は内側と外側の選択式となっております。
  * どちらを選択しても同じ動作をするように設計しています。
  
  * 使用するつまみ、または自身の手の大きさなどを考慮し自身で内側か外側かの選択を行ってください。
  * 取り付け位置選択後、PCB表面からロータリーエンコーダを取り付け、裏面からはんだ付けを行ってください。
* 9.トッププレートの取り付け
  * トッププレートの保護フィルムを剥がし、M2 3mmスペーサーをM2 8mmネジで固定してください。
  * その後、PCB表面に取り付け、サンドするようにM2 6mmスペーサーを裏面から取り付けてください。
* 10.保護プレート用スペーサーの取り付け
  * Pro Micro取り付け位置直下に位置する2箇所の穴に裏面からM2 4mmネジを入れ、M2 8mmスペーサーで固定してください。
* 11.ボトムプレートの取り付け
  * ボトムプレートの保護フィルムを剥がし、基板上でロータリーエンコーダの上部に位置する穴に対して裏面からM2 12mmネジを入れ、M2 6mmスペーサーで固定してください。
  * その後、M2 4mmネジ使用し残りの箇所を固定してください。
* 12.キースイッチの取り付け
  * 基盤にキースイッチを取り付けてください。
* 13.Pro Microの取り付け
  * Pro Microを取り付け、PCと接続し、キースイッチとロータリーエンコーダの入力の確認を行ってください。
* 14.OLEDモジュールの取り付け(オプション)
  * OLEDモジュールを取り付け、PCと接続し、表示されることの確認を行ってください。
  * デフォルトでは左側にはレイヤーとLEDの光度情報、右側は真っ白な長方形が表示されます。
* 15.保護プレートの取り付け
  * ロータリーエンコーダーを内側に取り付けた場合は外側用の、内側に取り付けた場合は外側用の保護プレートを使用します。
  * ロータリーエンコーダー上部に位置する箇所から飛び出ているネジにM2 8mmスペーサーを固定。
  * そして、保護フィルムを剥がし、表面からM2 4mmねじで保護プレートを固定してください。
* 16.つまみの取り付け
  * つまみをロータリーエンコーダーに取り付けてください。
* 17.キーキャップの取り付け
  * キースイッチにキーキャップを取り付けてください。
  * 使用するキーキャップについては[キーレイアウト](http://www.keyboard-layout-editor.com/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'%3B&@=Shift&=Z&=X&=C&=V&=B&_x:3.25%3B&=N&=M&=%3C%0A,&=%3E%0A.&=%3F%0A%2F%2F&=Shift%3B&@_x:3&w:1.5%3B&=RAISE&_w:1.5%3B&=Space&_x:3.25&w:1.5%3B&=Enter&_w:1.5%3B&=LOWER%3B&@_y:-0.75&x:6%3B&=TENKEY&_x:1.25%3B&=SECOND)を確認してください。
* 18.ゴム足の取り付け
  * ボトムプレートにゴム足を取り付けください。

組み立ての手順は、以上です。

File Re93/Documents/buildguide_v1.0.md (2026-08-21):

# Re93_Rev1.0 ビルドガイド
Re93

## ご購入前にお読みください

本製品をご購入いただいた時点で、下記「譲渡・再販について」の内容にご同意いただいたものとみなします。

### 譲渡・再販について

BOOTHや遊舎工房など、作者本人が販売または委託している場所以外で購入された場合、同梱品の不足や不良品への対応など、各種サポートをいたしかねます。  
そのため、以下のとおりお願いしております。

1. 本製品（完成品・未完成品・付属部品を問わず）を、ネットオークション、フリマサービス、その他の方法により第三者へ有償で譲渡することを禁止します。
2. 本項に反する行為を確認した場合、以後の販売をお断りする場合があります。

## はじめに
このたびはご購入いただきありがとうございます。  
本製品は組み立てが必要なキットです。  

Re93は親指で操作可能なロータリーエンコーダーを備え、プログラマーなどに人気の高いあの配列を踏襲した90％分割キーボードです。  
使用するキーキャップについては[キーレイアウト](http://www.keyboard-layout-editor.com/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'&_w:2.25%3B&=Enter&=%0A0%3B&@=%0A5&_w:2.25%3B&=Shift&=Z&=X&=C&=V&=B&_x:3.75%3B&=N&=M&=%3C%0A,&=%3E%0A.&=%3F%0A%2F%2F&_w:1.75%3B&=Shift&_a:7%3B&=%E2%86%91&_a:4%3B&=Fn%3B&@=%0A6&_w:1.5%3B&=Ctrl&=Fn&_w:1.5%3B&=GUI&_x:0.75&w:1.25%3B&=Space&_w:1.25%3B&=Space&_x:3&w:1.25%3B&=Space&_w:1.5%3B&=Space&_x:0.75&w:1.5%3B&=GUI&=ALT&_x:0.5&a:7%3B&=%E2%86%90&=%E2%86%93&=%E2%86%92%3B&@_y:-0.75&x:8.25&a:4%3B&=SECOND&_x:1%3B&=SECOND)を確認してください。  
※中央付近に突き出した1Uはロータリーエンコーダーのブッシュスイッチを表しています。  

写真は作成見本であり商品内容と同一ではありません。  
また仕様は予告なく変更されることがあります。  

ファームウェアに[qmk_firmware](https://github.com/qmk/qmk_firmware)を採用しています。  
QMKにRe93のコードはまだマージされていませんのでこの[ブランチ](https://github.com/kushima8/qmk_firmware/tree/re)を使用してください。  
動作確認の為にdefaultの[HEXファイル](https://github.com/kushima8/Re/blob/master/Re93/HEX)を用意しています。  
defaultを使用した場合、左側のPro MicroとPCを接続する設定となっております。  
右側で接続した場合はキーマップが反転します。  
反転せずに右側接続を行いたい場合は、右側最上段右端のキーを押下しながら接続することで対応可能です。  

キット作成前にPro Microの書き込み環境の構築を行ってください。  
ファームウェアの書き込み環境の構築については下記のサリチル酸さんのサイトを参考にしてください。  
[（初心者編）自作キーボードにファームウェアを書き込む](https://salicylic-acid3.hatenablog.com/entry/qmk-toolbox)  

キー割り当ての変更方法などはご自身でお調べいただくようお願いします。  

GUIから簡単にキー割り当てを変更できる[VIA](https://caniusevia.com/)と[Remap](https://remap-keys.app/)に対応しております。  
ロータリーエンコーダの回転割り当ても含め、設定できますのでご活用ください。  
VIAとRemapについては下記のサリチル酸さんのサイトを参考にしてください。  
[（初心者編）VIAを使ってキーマップを書き換えよう](https://salicylic-acid3.hatenablog.com/entry/via-manual)  
[（初心者編）Remapを使ってキーマップを書き換えよう](https://salicylic-acid3.hatenablog.com/entry/remap-manual)  
こちらのファームウェア[Re93_via.hex](https://github.com/kushima8/Re/blob/master/Re93/VIA/Re93_via.hex)を使用してください。  
[re93_via.hex](https://github.com/kushima8/Re/blob/master/Re93/VIA/re93_via.hex)ではロータリーエンコーダの初期割り当てが未設定ですので、動作確認時には[Remap](https://remap-keys.app/)などで割り当て設定をしてください。  

[プレートのデータ](https://github.com/kushima8/Re/tree/master/Re93/Plate)は公開中です。  
アルミプレートなど作成したい場合にお使いください。  

Type-C端子搭載のiPadと接続可能です。  
iPad mini 6にて簡易動作確認済みです。  
一部iPadでは対応していないキーコードがありますのでご注意ください。  

以下の部品リストを参考に欠品がないか確認をお願いします。  

## 部品

### キットに付属しているもの

|名称|数量|備考|
|----|:---:|----|
|PCB|2枚|右側用、左側用各1枚ずつ|
|トッププレート|2枚|右側用、左側用各1枚ずつ|
|ボトムプレート|2枚|右側用、左側用各1枚ずつ|
|保護プレート|4枚|内側用、外側用各2枚ずつ|
|M2 3mmスペーサー(ARB-2003E)|10個|丸型両メネジ|
|M2 6mmスペーサー(ARB-2006E)|12個|丸型両メネジ|
|M2 8mmスペーサー(ARB-2008E)|6個|丸型両メネジ|
|M2 4mmネジ|20本|
|M2 8mmネジ|10本|
|M2 12mmネジ|2本|
|ダイオード(1N4148/1N4148W)|95本/個|どちらかが同梱|
|Kailh PCB ソケット(MX用)|93個|
|タクトスイッチ|2個|
|TRRSジャック(MJ-4PP-9)|2個|
|プッシュスイッチ内蔵ロータリーエンコーダ(EC11E1834403)|2個|
|ゴム足|8個|
|DJ ミキサー用 つまみ  Chroma Caps Fatty Knob BLACK (180°)|1個|
|岩通アイセック ジョグダイヤルツマミ(黒)  R3310-6-SWA-11|1個|
|イモネジ|2個|ジョグダイヤル固定用|
|ステッカー|1枚|

### 別途、購入が必ず必要なもの
以下の部品は別途購入してください。

|名称|数量|備考|
|----|:---:|----|
|キースイッチ(Cherry MX互換)|93個|
|キーキャップ(Cherry MX互換)|93個|
|Pro Micro|2個|
|コンスルーピンヘッダ	|4個|
|TRRSケーブル|1本|
|2Uスタビライザー(Cherry MX互換)|2個|

## 組み立て
* Re64(Rev1)になりますが、Daihukuさんによるビルドログ動画があります。  
 作成手順が似ており、本機を作成するにあたって参考になると思いますので是非御覧ください。  
 https://www.youtube.com/watch?v=lg03LpNXRAI
* 表面  
  
* 裏面  
  
* 1.ヤスリがけ
  * 製造の都合上PCBにバリが存在します。
  
* 裏面  
  * この箇所を市販されている紙ヤスリなどで研磨してください。
* 2.Pro Microのはんだ付け
  * チップが載っている面が内側になるようにし、コンスルーピンヘッダを取り付けはんだ付けをしてください。
  * コンスルーピンヘッダには取り付け方向があるため気をつけてください。
  * [コンスルー - Self-Made Keyboards in Japan - ](https://scrapbox.io/self-made-kbds-ja/%E3%82%B3%E3%83%B3%E3%82%B9%E3%83%AB%E3%83%BC)  
  
* 3.ファームウェアの書き込み
  * [Re93_default.hex](https://github.com/kushima8/Re/blob/master/Re93/HEX/Re93_default.hex)を指定してファームウェアを書き込んでください。
* 4-1.ダイオードのはんだ付け(挿入実装の場合)
  * ダイオードの足を曲げ、PCB前面から取り付け、裏面からはんだ付けを行ってください。
  * ダイオードの向きは前面から見て左(三角形の頂点の先に縦棒がある方)に黒帯が来るように設置しはんだ付けを行ってください。
* 4-2.ダイオードのはんだ付け(表面実装の場合)
　* ダイオード取り付け箇所の片側に予めはんだを盛ります。
  * その後、表面に印刷がある方を表面にし、線が書いてある方を左(三角形の頂点の先に縦棒がある方)にセットします。
  * ダイオードをピンセットで持ちつつ、予めはんだを盛った箇所をはんだごてで加熱して片側だけはんだ付けを行います。
  * 片側のはんだ付けが完了後、もう片方もはんだ付けを行ってください。
* 5.Kailh PCB ソケット
  * 中央の穴に干渉しないようにソケットを設置してください。
  * ソケットの片側はんだ付けをしっかりと行い、基盤から浮いていないようであればもう片方もはんだ付けをしっかりと行ってください。
* 6.タクトスイッチ、TRRSジャックのはんだ付け
  * PCB表面から取り付け、裏面からはんだ付けを行ってください。
* 7.ロータリーエンコーダのはんだ付け
  * ロータリーエンコーダーの取り付け位置は内側と外側の選択式となっております。
  * どちらを選択しても同じ動作をするように設計しています。
  
  * 使用するつまみ、または自身の手の大きさなどを考慮し自身で内側か外側かの選択を行ってください。
  * 取り付け位置選択後、PCB表面からロータリーエンコーダを取り付け、裏面からはんだ付けを行ってください。
* 8.スタビライザーの取り付け
  * 基盤にスタビライザーを取り付けてください。
* 9.トッププレートの取り付け
  * トッププレートの保護フィルムを剥がし、M2 3mmスペーサーをM2 8mmネジで固定してください。
  * その後、PCB表面に取り付け、サンドするようにM2 6mmスペーサーを裏面から取り付けてください。
* 10.保護プレート用スペーサーの取り付け
  * Pro Micro取り付け位置直下に位置する2箇所の穴に裏面からM2 4mmネジを入れ、M2 8mmスペーサーで固定してください。
* 11.ボトムプレートの取り付け
  * ボトムプレートの保護フィルムを剥がし、基板上でロータリーエンコーダの上部に位置する穴に対して裏面からM2 12mmネジを入れ、M2 6mmスペーサーで固定してください。
  * その後、M2 4mmネジを仕様し残りの箇所を固定してください。
* 12.キースイッチの取り付け
  * 基盤にキースイッチを取り付けてください。
* 13.Pro Microの取り付け
  * Pro Microを取り付け、PCと接続し、キースイッチとロータリーエンコーダの入力の確認を行ってください。
* 14.保護プレートの取り付け
  * ロータリーエンコーダーを内側に取り付けた場合は外側用の、内側に取り付けた場合は外側用の保護プレートを使用します。
  * ロータリーエンコーダー上部に位置する箇所から飛び出ているネジにM2 8mmスペーサーを固定。
  * そして、保護フィルムを剥がし、表面からM2 4mmねじで保護プレートを固定してください。
* 15.つまみの取り付け
  * つまみをロータリーエンコーダーに取り付けてください。
* 16.キーキャップの取り付け
  * キースイッチにキーキャップを取り付けてください。
  * 使用するキーキャップについては[キーレイアウト](http://www.keyboard-layout-editor.com/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'&_w:2.25%3B&=Enter&=%0A0%3B&@=%0A5&_w:2.25%3B&=Shift&=Z&=X&=C&=V&=B&_x:3.75%3B&=N&=M&=%3C%0A,&=%3E%0A.&=%3F%0A%2F%2F&_w:1.75%3B&=Shift&_a:7%3B&=%E2%86%91&_a:4%3B&=Fn%3B&@=%0A6&_w:1.5%3B&=Ctrl&=Fn&_w:1.5%3B&=GUI&_x:0.75&w:1.25%3B&=Space&_w:1.25%3B&=Space&_x:3&w:1.25%3B&=Space&_w:1.5%3B&=Space&_x:0.75&w:1.5%3B&=GUI&=ALT&_x:0.5&a:7%3B&=%E2%86%90&=%E2%86%93&=%E2%86%92%3B&@_y:-0.75&x:8.25&a:4%3B&=SECOND&_x:1%3B&=SECOND)を確認してください。
* 17.ゴム足の取り付け
  * ボトムプレートにゴム足を取り付けください。

組み立ての手順は、以上です。

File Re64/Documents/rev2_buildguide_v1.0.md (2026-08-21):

# Re64_Rev2.0 ビルドガイド
Re64_rev2

## ご購入前にお読みください

本製品をご購入いただいた時点で、下記「譲渡・再販について」の内容にご同意いただいたものとみなします。

### 譲渡・再販について

BOOTHや遊舎工房など、作者本人が販売または委託している場所以外で購入された場合、同梱品の不足や不良品への対応など、各種サポートをいたしかねます。  
そのため、以下のとおりお願いしております。

1. 本製品（完成品・未完成品・付属部品を問わず）を、ネットオークション、フリマサービス、その他の方法により第三者へ有償で譲渡することを禁止します。
2. 本項に反する行為を確認した場合、以後の販売をお断りする場合があります。

## はじめに
このたびはご購入いただきありがとうございます。  
本製品は組み立てが必要なキットです。  

Re64_Rev2は親指で操作可能なロータリーエンコーダーを備え、プログラマーなどに人気の高いあの配列を踏襲した60％分割キーボードです。  
使用するキーキャップについては[キーレイアウト](http://www.keyboard-layout-editor.com/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'&_w:2.25%3B&=Enter%3B&@_w:2.25%3B&=Shift&=Z&=X&=C&=V&=B&_x:3.75%3B&=N&=M&=%3C%0A,&=%3E%0A.&=%3F%0A%2F%2F&_w:1.75%3B&=Shift&=Fn%3B&@_w:1.5%3B&=Ctrl&=Fn&_w:1.5%3B&=GUI&_x:0.75&w:1.25%3B&=Space&_w:1.25%3B&=Space&_x:3&w:1.25%3B&=Space&_w:1.5%3B&=Space&_x:0.75&w:1.5%3B&=GUI&=ALT%3B&@_y:-0.75&x:7.25%3B&=SECOND&_x:1%3B&=SECOND)を確認してください。  
※中央付近に突き出した1Uはロータリーエンコーダーのブッシュスイッチを表しています。  

写真は作成見本であり商品内容と同一ではありません。  
また仕様は予告なく変更されることがあります。  

ファームウェアに[qmk_firmware](https://github.com/qmk/qmk_firmware)を採用しています。  
QMKにRe64_Rev2のコードはまだマージされていませんのでこの[ブランチ](https://github.com/kushima8/qmk_firmware/tree/re)を使用してください。  
動作確認の為にdefaultの[HEXファイル](https://github.com/kushima8/Re/blob/master/Re64/HEX)を用意しています。  
defaultを使用した場合、左側のPro MicroとPCを接続する設定となっております。  
右側で接続した場合はキーマップが反転します。  
反転せずに右側接続を行いたい場合は、右側最上段右端のキーを押下しながら接続することで対応可能です。  

キット作成前にPro Microの書き込み環境の構築を行ってください。  
ファームウェアの書き込み環境の構築については下記のサリチル酸さんのサイトを参考にしてください。  
[（初心者編）自作キーボードにファームウェアを書き込む](https://salicylic-acid3.hatenablog.com/entry/qmk-toolbox)  

キー割り当ての変更方法などはご自身でお調べいただくようお願いします。  

GUIから簡単にキー割り当てを変更できる[VIA](https://caniusevia.com/)と[Remap](https://remap-keys.app/)に対応しております。  
ロータリーエンコーダの回転割り当ても含め、設定できますのでご活用ください。  
VIAとRemapについては下記のサリチル酸さんのサイトを参考にしてください。  
[（初心者編）VIAを使ってキーマップを書き換えよう](https://salicylic-acid3.hatenablog.com/entry/via-manual)  
[（初心者編）Remapを使ってキーマップを書き換えよう](https://salicylic-acid3.hatenablog.com/entry/remap-manual)  
OLEDを接続していない場合は[re64_via.hex](https://github.com/kushima8/Re/blob/master/Re64/VIA/re64_via.hex)を、  
接続している場合は[re64_via_oled.hex](https://github.com/kushima8/Re/blob/master/Re64/VIA/re64_via_oled.hex)を使用してください。  
[re64_via.hex](https://github.com/kushima8/Re/blob/master/Re64/VIA/re64_via.hex)と[re64_via_oled.hex](https://github.com/kushima8/Re/blob/master/Re64/VIA/re64_via_oled.hex)ではロータリーエンコーダの初期割り当てが未設定ですので、動作確認時には[Remap](https://remap-keys.app/)などで割り当て設定をしてください。  

[プレートのデータ](https://github.com/kushima8/Re/tree/master/Re64/Plate)は公開中です。  
アルミプレートなど作成したい場合にお使いください。  

Type-C端子搭載のiPadと接続可能です。  
iPad mini 6にて簡易動作確認済みです。  
一部iPadでは対応していないキーコードがありますのでご注意ください。  

以下の部品リストを参考に欠品がないか確認をお願いします。  

## 部品

### キットに付属しているもの

|名称|数量|備考|
|----|:---:|----|
|PCB|2枚|右側用、左側用各1枚ずつ|
|トッププレート|2枚|右側用、左側用各1枚ずつ|
|ボトムプレート|2枚|右側用、左側用各1枚ずつ|
|保護プレート|4枚|内側用、外側用各2枚ずつ|
|M2 3mmスペーサー(ARB-2003E)|10個|丸型両メネジ|
|M2 6mmスペーサー(ARB-2006E)|12個|丸型両メネジ|
|M2 8mmスペーサー(ARB-2008E)|6個|丸型両メネジ|
|M2 4mmネジ|20本|
|M2 8mmネジ|10本|
|M2 12mmネジ|2本|
|ダイオード(1N4148/1N4148W)|66本/個|どちらかが同梱|
|Kailh PCB ソケット(MX用)|64個|
|タクトスイッチ|2個|
|TRRSジャック(MJ-4PP-9)|2個|
|プッシュスイッチ内蔵ロータリーエンコーダ(EC11E1834403/PEC12R-4222F-S0024)|2個|どちらかが同梱
|ゴム足|8個|
|DJ ミキサー用 つまみ  Chroma Caps Fatty Knob BLACK (180°)|1個|
|岩通アイセック ジョグダイヤルツマミ(黒)  R3310-6-SWA-11|1個|
|イモネジ|2個|ジョグダイヤル固定用|
|ステッカー|1枚|

### 別途、購入が必ず必要なもの
以下の部品は別途購入してください。

|名称|数量|備考|
|----|:---:|----|
|キースイッチ(Cherry MX互換)|64個|
|キーキャップ(Cherry MX互換)|64個|
|Pro Micro|2個|
|コンスルーピンヘッダ	|4個|
|TRRSケーブル|1本|
|2Uスタビライザー(Cherry MX互換)|2個|

### オプション
以下の部品はオプション品です。
キーボードを光らせたいなどの場合のみ別途購入してください。

|名称|数量|備考|
|----|:---:|----|
|LEDチップ(YS-SK6812MINI-E)|76個|
|OLEDモジュール|2個|
|OLED用ピンソケット|2個|

## 組み立て
* Re64(Rev1)になりますが、Daihukuさんによるビルドログ動画があります。  
 作成手順が似ており、本機を作成するにあたって参考になると思いますので是非御覧ください。  
 https://www.youtube.com/watch?v=lg03LpNXRAI
* 表面  
  
* 裏面  
  
* 1.ヤスリがけ
  * 製造の都合上PCBにバリが存在します。
  
* 裏面  
  * この箇所を市販されている紙ヤスリなどで研磨してください。
* 2.Pro Microのはんだ付け
  * チップが載っている面が内側になるようにし、コンスルーピンヘッダを取り付けはんだ付けをしてください。
  * コンスルーピンヘッダには取り付け方向があるため気をつけてください。
  * [コンスルー - Self-Made Keyboards in Japan - ](https://scrapbox.io/self-made-kbds-ja/%E3%82%B3%E3%83%B3%E3%82%B9%E3%83%AB%E3%83%BC)  
  
* 3.ファームウェアの書き込み
  * [re64_default.hex](https://github.com/kushima8/Re/blob/master/Re64/HEX/re64_default.hex)を指定してファームウェアを書き込んでください。
  * OLEDを使用する場合は'rules.mk'内の'OLED_DRIVER_ENABLE'を'yes'に書き換え、ご自身で環境を作っていただきファームウェアをコンパイルして頂くか、
  * もしくは[re64_via_oled.hex](https://github.com/kushima8/Re/blob/master/Re64/VIA/re64_via_oled.hex)を指定してファームウェアを書き込んでください。
  * [re64_via_oled.hex](https://github.com/kushima8/Re/blob/master/Re64/VIA/re64_via_oled.hex)ではロータリーエンコーダの初期割り当てが未設定ですので、動作確認時には[Remap](https://remap-keys.app/)などで割り当て設定をしてください。
* 4.LEDチップのはんだ付け(オプション)
  * LEDチップ((YS-SK6812MINI-E)はPCBを裏面(LED取り付け穴が上に来るように)にして右下から左上へZ字の書き順とは逆になるように実装してください。
  * その後表面(LED取り付け穴が上に来るように)にし右下から左上へZ字の書き順とは逆になるように実装してください。
  * 高い温度ではんだ付けを行うとLED破損の可能性がありますので、約270℃に設定してはんだ付けをするようにしてください。
  * LEDは足が欠けている箇所が左下にあるシルクのマークの位置に来るように設置し、はんだ付けを行ってください。
  * はんだ付けが完了したら一度Pro Microを取り付け、LEDが光るかどうかテストを行ってください。  
  
* 5-1.ダイオードのはんだ付け(挿入実装の場合)
  * ダイオードの足を曲げ、PCB前面から取り付け、裏面からはんだ付けを行ってください。
  * ダイオードの向きは前面から見て左(三角形の頂点の先に縦棒がある方)に黒帯が来るように設置しはんだ付けを行ってください。
* 5-2.ダイオードのはんだ付け(表面実装の場合)
　* ダイオード取り付け箇所の片側に予めはんだを盛ります。
  * その後、表面に印刷がある方を表面にし、線が書いてある方を左(三角形の頂点の先に縦棒がある方)にセットします。
  * ダイオードをピンセットで持ちつつ、予めはんだを盛った箇所をはんだごてで加熱して片側だけはんだ付けを行います。
  * 片側のはんだ付けが完了後、もう片方もはんだ付けを行ってください。
* 6.Kailh PCB ソケット
  * 中央の穴に干渉しないようにソケットを設置してください。
  * ソケットの片側はんだ付けをしっかりと行い、基盤から浮いていないようであればもう片方もはんだ付けをしっかりと行ってください。
* 7.タクトスイッチ、TRRSジャックのはんだ付け
  * PCB表面から取り付け、裏面からはんだ付けを行ってください。
* 8.OLEDモジュール、OLED用ピンソケットのはんだ付け(オプション)
  * OLEDモジュールとピンヘッダのハンダ付けを行ってください。
  * ピンソケットをPCB表面から取り付け、裏面からはんだ付けを行ってください。
* 9.ロータリーエンコーダのはんだ付け
  * ロータリーエンコーダーの取り付け位置は内側と外側の選択式となっております。
  * どちらを選択しても同じ動作をするように設計しています。
  
  * 使用するつまみ、または自身の手の大きさなどを考慮し自身で内側か外側かの選択を行ってください。
  * 取り付け位置選択後、PCB表面からロータリーエンコーダを取り付け、裏面からはんだ付けを行ってください。
* 10.スタビライザーの取り付け
  * 基盤にスタビライザーを取り付けてください。
* 11.トッププレートの取り付け
  * トッププレートの保護フィルムを剥がし、M2 3mmスペーサーをM2 8mmネジで固定してください。
  * その後、PCB表面に取り付け、サンドするようにM2 6mmスペーサーを裏面から取り付けてください。
* 12.保護プレート用スペーサーの取り付け
  * Pro Micro取り付け位置直下に位置する2箇所の穴に裏面からM2 4mmネジを入れ、M2 8mmスペーサーで固定してください。
* 13.ボトムプレートの取り付け
  * ボトムプレートの保護フィルムを剥がし、基板上でロータリーエンコーダの上部に位置する穴に対して裏面からM2 12mmネジを入れ、M2 6mmスペーサーで固定してください。
  * その後、M2 4mmネジを仕様し残りの箇所を固定してください。
* 14.キースイッチの取り付け
  * 基盤にキースイッチを取り付けてください。
* 15.Pro Microの取り付け
  * Pro Microを取り付け、PCと接続し、キースイッチとロータリーエンコーダの入力の確認を行ってください。
* 16.OLEDモジュールの取り付け(オプション)
  * OLEDモジュールを取り付け、PCと接続し、表示されることの確認を行ってください。
  * デフォルトでは左側にはレイヤーとLEDの光度情報、右側は真っ白な長方形が表示されます。
* 17.保護プレートの取り付け
  * ロータリーエンコーダーを内側に取り付けた場合は外側用の、内側に取り付けた場合は外側用の保護プレートを使用します。
  * ロータリーエンコーダー上部に位置する箇所から飛び出ているネジにM2 8mmスペーサーを固定。
  * そして、保護フィルムを剥がし、表面からM2 4mmねじで保護プレートを固定してください。
* 18.つまみの取り付け
  * つまみをロータリーエンコーダーに取り付けてください。
* 19.キーキャップの取り付け
  * キースイッチにキーキャップを取り付けてください。
  * 使用するキーキャップについては[キーレイアウト](http://www.keyboard-layout-editor.com/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'&_w:2.25%3B&=Enter%3B&@_w:2.25%3B&=Shift&=Z&=X&=C&=V&=B&_x:3.75%3B&=N&=M&=%3C%0A,&=%3E%0A.&=%3F%0A%2F%2F&_w:1.75%3B&=Shift&=Fn%3B&@_w:1.5%3B&=Ctrl&=Fn&_w:1.5%3B&=GUI&_x:0.75&w:1.25%3B&=Space&_w:1.25%3B&=Space&_x:3&w:1.25%3B&=Space&_w:1.5%3B&=Space&_x:0.75&w:1.5%3B&=GUI&=ALT%3B&@_y:-0.75&x:7.25%3B&=SECOND&_x:1%3B&=SECOND)を確認してください。
* 20.ゴム足の取り付け
  * ボトムプレートにゴム足を取り付けください。

組み立ての手順は、以上です。

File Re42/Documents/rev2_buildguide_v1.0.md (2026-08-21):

# Re42_Rev2.0 ビルドガイド
Re42_rev2

## ご購入前にお読みください

本製品をご購入いただいた時点で、下記「譲渡・再販について」の内容にご同意いただいたものとみなします。

### 譲渡・再販について

BOOTHや遊舎工房など、作者本人が販売または委託している場所以外で購入された場合、同梱品の不足や不良品への対応など、各種サポートをいたしかねます。  
そのため、以下のとおりお願いしております。

1. 本製品（完成品・未完成品・付属部品を問わず）を、ネットオークション、フリマサービス、その他の方法により第三者へ有償で譲渡することを禁止します。
2. 本項に反する行為を確認した場合、以後の販売をお断りする場合があります。

## はじめに
このたびはご購入いただきありがとうございます。  
本製品は組み立てが必要なキットです。  

Re42_Rev2は親指で操作可能なロータリーエンコーダーを備える40％分割キーボードです。  
使用するキーキャップについては[キーレイアウト](http://www.keyboard-layout-editor.com/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'%3B&@=Shift&=Z&=X&=C&=V&=B&_x:3.25%3B&=N&=M&=%3C%0A,&=%3E%0A.&=%3F%0A%2F%2F&=Shift%3B&@_a:7&w:1.5%3B&=&_x:1.75&a:4&w:1.5%3B&=RAISE&_w:1.25%3B&=Space&_x:3.25&w:1.25%3B&=Enter&_w:1.5%3B&=LOWER&_x:1.75&a:7&w:1.5%3B&=%3B&@_y:-0.75&x:6&a:4%3B&=TENKEY&_x:1.25%3B&=SECOND)を確認してください。  
※中央付近に突き出した1Uはロータリーエンコーダーのブッシュスイッチを表しています。  

写真は作成見本であり商品内容と同一ではありません。  
また仕様は予告なく変更されることがあります。  

ファームウェアに[qmk_firmware](https://github.com/qmk/qmk_firmware)を採用しています。  
QMKにRe42_Rev2のコードはまだマージされていませんのでこの[ブランチ](https://github.com/kushima8/qmk_firmware/tree/re)を使用してください。  
動作確認の為にdefaultの[HEXファイル](https://github.com/kushima8/Re/blob/master/Re42/HEX)を用意しています。  
defaultを使用した場合、左側右側どちらのPro MicroでもPCを接続可能な設定となっております。  

キット作成前にPro Microの書き込み環境の構築を行ってください。  
ファームウェアの書き込み環境の構築については下記のサリチル酸さんのサイトを参考にしてください。  
[（初心者編）自作キーボードにファームウェアを書き込む](https://salicylic-acid3.hatenablog.com/entry/qmk-toolbox)  

キー割り当ての変更方法などはご自身でお調べいただくようお願いします。  

GUIから簡単にキー割り当てを変更できる[VIA](https://caniusevia.com/)と[Remap](https://remap-keys.app/)に対応しております。  
ロータリーエンコーダの回転割り当ても含め、設定できますのでご活用ください。  
VIAとRemapについては下記のサリチル酸さんのサイトを参考にしてください。  
[（初心者編）VIAを使ってキーマップを書き換えよう](https://salicylic-acid3.hatenablog.com/entry/via-manual)  
[（初心者編）Remapを使ってキーマップを書き換えよう](https://salicylic-acid3.hatenablog.com/entry/remap-manual)  
OLEDを接続していない場合は[re42_via.hex](https://github.com/kushima8/Re/blob/master/Re42_/VIA/re42_via.hex)を、  
接続している場合は[re42_via_oled.hex](https://github.com/kushima8/Re/blob/master/Re42/VIA/re42_via_oled.hex)を使用してください。  
[re42_via.hex](https://github.com/kushima8/Re/blob/master/Re42/VIA/re42_via.hex)と[re42_via_oled.hex](https://github.com/kushima8/Re/blob/master/Re42/VIA/re42_via_oled.hex)ではロータリーエンコーダの初期割り当てが未設定ですので、動作確認時には[Remap](https://remap-keys.app/)などで割り当て設定をしてください。  

[プレートのデータ](https://github.com/kushima8/Re/tree/master/Re42/Plate)は公開中です。  
アルミプレートなど作成したい場合にお使いください。  

Type-C端子搭載のiPadと接続可能です。  
iPad mini 6にて簡易動作確認済みです。  
一部iPadでは対応していないキーコードがありますのでご注意ください。  

以下の部品リストを参考に欠品がないか確認をお願いします。  

## 部品

### キットに付属しているもの

|名称|数量|備考|
|----|:---:|----|
|PCB|2枚|右側用、左側用各1枚ずつ|
|トッププレート|2枚|右側用、左側用各1枚ずつ|
|ボトムプレート|2枚|右側用、左側用各1枚ずつ|
|保護プレート|4枚|内側用、外側用各2枚ずつ|
|M2 3mmスペーサー(ARB-2003E)|10個|丸型両メネジ|
|M2 6mmスペーサー(ARB-2006E)|12個|丸型両メネジ|
|M2 8mmスペーサー(ARB-2008E)|6個|丸型両メネジ|
|M2 4mmネジ|20本|
|M2 8mmネジ|10本|
|M2 12mmネジ|2本|
|ダイオード(1N4148/1N4148W)|44本/個|どちらかが同梱|
|Kailh PCB ソケット(MX用)|42個|
|タクトスイッチ|2個|
|TRRSジャック(MJ-4PP-9)|2個|
|プッシュスイッチ内蔵ロータリーエンコーダ(EC11E1834403)|2個|
|ゴム足|8個|
|DJ ミキサー用 つまみ  Chroma Caps Fatty Knob BLACK (180°)|1個|
|岩通アイセック ジョグダイヤルツマミ(黒)  R3310-6-SWA-11|1個|
|イモネジ|2個|ジョグダイヤル固定用|
|ステッカー|1枚|

### 別途、購入が必ず必要なもの
以下の部品は別途購入してください。

|名称|数量|備考|
|----|:---:|----|
|キースイッチ(Cherry MX互換)|42個|
|キーキャップ(Cherry MX互換)|42個|
|Pro Micro|2個|
|コンスルーピンヘッダ	|4個|
|TRRSケーブル|1本|

### オプション
以下の部品はオプション品です。
キーボードを光らせたいなどの場合のみ別途購入してください。

|名称|数量|備考|
|----|:---:|----|
|LEDチップ(YS-SK6812MINI-E)|54個|
|OLEDモジュール|2個|
|OLED用ピンソケット|2個|

## 組み立て
* Re64(Rev1)になりますが、Daihukuさんによるビルドログ動画があります。
  作成手順が似ており、本機を作成するにあたって参考になると思いますので是非御覧ください。
　https://www.youtube.com/watch?v=lg03LpNXRAI
* 表面  
    
* 裏面  
    
* 1.ヤスリがけ
  * 製造の都合上PCBにバリが存在します。
  
* 裏面  
  * この箇所を市販されている紙ヤスリなどで研磨してください。
* 2.Pro Microのはんだ付け
  * チップが載っている面が内側になるようにし、コンスルーピンヘッダを取り付けはんだ付けをしてください。
  * コンスルーピンヘッダには取り付け方向があるため気をつけてください。
  * [コンスルー - Self-Made Keyboards in Japan - ](https://scrapbox.io/self-made-kbds-ja/%E3%82%B3%E3%83%B3%E3%82%B9%E3%83%AB%E3%83%BC)  
  
* 3.ファームウェアの書き込み
  * [re42_default.hex](https://github.com/kushima8/Re/blob/master/Re42/HEX/re42_default.hex)を指定してファームウェアを書き込んでください。
  * OLEDを使用する場合は'rules.mk'内の'OLED_DRIVER_ENABLE'を'yes'に書き換え、ご自身で環境を作っていただきファームウェアをコンパイルして頂くか、
  * もしくは[re42_via_oled.hex](https://github.com/kushima8/Re/blob/master/Re42/VIA/re42_via_oled.hex)を指定してファームウェアを書き込んでください。
  * [re42_via_oled.hex](https://github.com/kushima8/Re/blob/master/Re40/VIA/re40_via_oled.hex)ではロータリーエンコーダの初期割り当てが未設定ですので、動作確認時には[Remap](https://remap-keys.app/)などで割り当て設定をしてください。
* 4.LEDチップのはんだ付け(オプション)
  * LEDチップ((YS-SK6812MINI-E)はPCBを裏面(LED取り付け穴が上に来るように)にして右下から左上へZ字の書き順とは逆になるように実装してください。
  * その後表面(LED取り付け穴が上に来るように)にし右下から左上へZ字の書き順とは逆になるように実装してください。
  * 高い温度ではんだ付けを行うとLED破損の可能性がありますので、約270℃に設定してはんだ付けをするようにしてください。
  * LEDは足が欠けている箇所が左下にあるシルクのマークの位置に来るように設置し、はんだ付けを行ってください。
  * はんだ付けが完了したら一度Pro Microを取り付け、LEDが光るかどうかテストを行ってください。  
  
* 5-1.ダイオードのはんだ付け(挿入実装の場合)
  * ダイオードの足を曲げ、PCB前面から取り付け、裏面からはんだ付けを行ってください。
  * ダイオードの向きは前面から見て左(三角形の頂点の先に縦棒がある方)に黒帯が来るように設置しはんだ付けを行ってください。
* 5-2.ダイオードのはんだ付け(表面実装の場合)
　* ダイオード取り付け箇所の片側に予めはんだを盛ります。
  * その後、表面に印刷がある方を表面にし、線が書いてある方を左(三角形の頂点の先に縦棒がある方)にセットします。
  * ダイオードをピンセットで持ちつつ、予めはんだを盛った箇所をはんだごてで加熱して片側だけはんだ付けを行います。
  * 片側のはんだ付けが完了後、もう片方もはんだ付けを行ってください。
* 6.Kailh PCB ソケット
  * 中央の穴に干渉しないようにソケットを設置してください。
  * ソケットの片側はんだ付けをしっかりと行い、基盤から浮いていないようであればもう片方もはんだ付けをしっかりと行ってください。
* 7.タクトスイッチ、TRRSジャックのはんだ付け
  * PCB表面から取り付け、裏面からはんだ付けを行ってください。
* 8.OLEDモジュール、OLED用ピンソケットのはんだ付け(オプション)
  * OLEDモジュールとピンヘッダのハンダ付けを行ってください。
  * ピンソケットをPCB表面から取り付け、裏面からはんだ付けを行ってください。
* 9.ロータリーエンコーダのはんだ付け
  * ロータリーエンコーダーの取り付け位置は内側と外側の選択式となっております。
  * どちらを選択しても同じ動作をするように設計しています。
  
  * 使用するつまみ、または自身の手の大きさなどを考慮し自身で内側か外側かの選択を行ってください。
  * 取り付け位置選択後、PCB表面からロータリーエンコーダを取り付け、裏面からはんだ付けを行ってください。
* 10.トッププレートの取り付け
  * トッププレートの保護フィルムを剥がし、M2 3mmスペーサーをM2 8mmネジで固定してください。
  * その後、PCB表面に取り付け、サンドするようにM2 6mmスペーサーを裏面から取り付けてください。
* 11.保護プレート用スペーサーの取り付け
  * Pro Micro取り付け位置直下に位置する2箇所の穴に裏面からM2 4mmネジを入れ、M2 8mmスペーサーで固定してください。
* 12.ボトムプレートの取り付け
  * ボトムプレートの保護フィルムを剥がし、基板上でロータリーエンコーダの上部に位置する穴に対して裏面からM2 12mmネジを入れ、M2 6mmスペーサーで固定してください。
  * その後、M2 4mmネジ使用し残りの箇所を固定してください。
* 13.キースイッチの取り付け
  * 基盤にキースイッチを取り付けてください。
* 14.Pro Microの取り付け
  * Pro Microを取り付け、PCと接続し、キースイッチとロータリーエンコーダの入力の確認を行ってください。
* 15.OLEDモジュールの取り付け(オプション)
  * OLEDモジュールを取り付け、PCと接続し、表示されることの確認を行ってください。
  * デフォルトでは左側にはレイヤーとLEDの光度情報、右側は真っ白な長方形が表示されます。
* 16.保護プレートの取り付け
  * ロータリーエンコーダーを内側に取り付けた場合は外側用の、内側に取り付けた場合は外側用の保護プレートを使用します。
  * ロータリーエンコーダー上部に位置する箇所から飛び出ているネジにM2 8mmスペーサーを固定。
  * そして、保護フィルムを剥がし、表面からM2 4mmねじで保護プレートを固定してください。
* 17.つまみの取り付け
  * つまみをロータリーエンコーダーに取り付けてください。
* 18.キーキャップの取り付け
  * キースイッチにキーキャップを取り付けてください。
  * 使用するキーキャップについては[キーレイアウト](http://www.keyboard-layout-editor.com/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'%3B&@=Shift&=Z&=X&=C&=V&=B&_x:3.25%3B&=N&=M&=%3C%0A,&=%3E%0A.&=%3F%0A%2F%2F&=Shift%3B&@_a:7&w:1.5%3B&=&_x:1.75&a:4&w:1.5%3B&=RAISE&_w:1.25%3B&=Space&_x:3.25&w:1.25%3B&=Enter&_w:1.5%3B&=LOWER&_x:1.75&a:7&w:1.5%3B&=%3B&@_y:-0.75&x:6&a:4%3B&=TENKEY&_x:1.25%3B&=SECOND)を確認してください。
* 19.ゴム足の取り付け
  * ボトムプレートにゴム足を取り付けください。

組み立ての手順は、以上です。

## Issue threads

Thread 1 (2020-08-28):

The spacers were not included in Re40.

corelax-dev, 2020-08-28:
I bought it at Yushu-kobo last week.But I couldn't find out the parts of the all spacers.

Please send me that.

kushima8, 2020-08-31:
Sorry for the delay in realizing this.
First of all, I want to apologize for the missing items.
I'd like to send you the missing spacers.
I want to keep in touch with Twitter DirectMessage, is that okay?
Twitter:@kushima8

corelax-dev, 2020-09-02:
Thank you for your support. I got spacers from you today.

Closed 2020-09-02.

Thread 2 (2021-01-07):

スペーサーのフットプリントが、現実に流通しているものよりも小さいケースがある(かもしれない)

koron, 2021-01-07:
### 経緯

1. re64l_bottom.dxf を本レポジトリよりダウンロードした
2. Jw_cad (8.22d) を用いて DXF に以下の修正を加えた
    * 全体を25.4倍に拡大し、単位をmmに変換した
    * 寸法線とその表記数値を削除した
    以上2点。加工会社の [ガイドライン](https://www.laserboost.com/design-guidelines) に従った修正
3. ステップ2で作成したDXFで業者に発注した
4. できてきたトッププレートを付けたところスタビライザー部分が装着できなかった
5. 0.1~0.2mmほど外側に向け、両端を削り広げることで装着した

### 計測など調査した情報

計測対象は左のトッププレートです。
DXF内のサイズはJw_cadを用いて `線長` および `測定` を用いて計測しました。

計測・調査対象 | `a` | `b` | `w` | `h` | 備考
---|---|---|---|---|--
オリジナルDXF | 0.265746in (6.75mm) | 1.20205in (30.53mm) | 0.5511in (14.0mm) | 0.5511in (14.0mm) | カッコ内は25.4倍してmm換算した値
加工後のDXF | 6.7499mm | 30.50mm | 13.999mm | 13.999mm | オリジナルのサイズを正確に表している
今回作成したアルミ | 6.7mm | 30.6mm | 14.0mm | 14.1mm | 若干怪しいところもあるがほぼ提出したDXF通りと言ってよい
アクリル(使用済) | 7.0mm | 30.8mm | 14.2mm | 14.2mm | 使用済みのため変形の可能性は否めない
[仕様書](https://github.com/kushima8/Re/files/5781624/MX.Series.pdf) からの抜粋 | 0.262±0.004in (6.65±0.10mm) | 0.94in+0.166in*2=1.272in (32.31mm) | 0.551in (14.0mm) | 0.551in (14.0mm) | `b` が実際よりもかなり広いのが謎。図面を読み間違えている可能性あり
使用しているスタビライザー | 6.8mm | 30.8mm | N/A | N/A | `b` は取り付けた状態での計測なのであまり意味はないが、今回作成したアルミがそのままでは入らないことがわかる。キースイッチは問題なく取り付けられている。

記号の意味:

* `a` - スタビライザーに2個付いたケーシングの幅
* `b` - スタビライザー穴の主幅(突出部分を含まない)
* `w` - キースイッチの穴の幅
* `h` - キースイッチの穴の高さ

以下は上記の計測場所を表す模式図

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

### 考察

* オリジナルDXFと加工済みDXF、および実際にできたアルミトッププレートは誤差の範囲内
    * 上記を3点を仕様と照らし合わせても、謎な `b` を除いて不審な点はない
* [仕様書](https://github.com/kushima8/Re/files/5781624/MX.Series.pdf) と比較すると実際に利用したスタビライザーの片足の幅が広すぎる
* 実物のアクリルトッププレートは `a`, `b`, `w`, `h` すべてがオリジナルDXFと(大きい方向で)異なる
    * ゆえに同じスタビライザーを用いても装着できる
    * これが何に由来しているかは不明: キットのモノと本レポジトリにあるデータは別物?

### 各種情報

* アルミ加工会社: [LASER BOOST](https://www.laserboost.com/)
    * 1.5mm のアルミ(A5754使用)
    * SandBlasting仕上げ
    下記 re64l_top_x25_4.dxf の注文時情報
    ```
    Material: Aluminium 5754 SandBlasted
    Thickness: 1.5 mm
    Size: 138.16 x 103.81 mm
    Path Length: 2270.87 mm
    ```

    アクリルの実測値が  137.9mm x 103.5mm であったため問題なしと判断

* 使ったスタビライザー: [遊舎工房 MXスイッチスタビライザー 2u](https://yushakobo.jp/shop/a0500st/)
* スタビライザーの位置: 左側のシフトキー相当部分(R4 最左)
* DXFファイル: [re64l_top.zip](https://github.com/kushima8/Re/files/5781459/re64l_top.zip)
    ZIP内は以下の2ファイルが入ってます。
    * re64l_top.dxf オリジナルファイル。 [Re64/Plate/re64l_bottom.dxf](https://github.com/kushima8/Re/blob/0bae5dc5c3ff40ee3f0fa1444f8c82efd387edbd/Re64/Plate/re64l_bottom.dxf) より 2020-12-28 に取得
    * re64l_top_x25_4.dxf Jw_catを使って加工済み。加工内容は以下の通り
        * mm単位にするために全体を25.4倍にした
        * 長さ指示の表示を消した
* [MX Series.pdf](https://github.com/kushima8/Re/files/5781624/MX.Series.pdf) - どこかで見つけてきた Cherry MX の仕様書(?)。 Metal Frame Cutout Dimensions がある

koron, 2021-01-07:
仕様書の `b` 相当の 0.166in は 0.133in の typo だったりしないだろうか?
だとすれば 1.206in (30.63mm) となり実体と合致する。

koron, 2021-01-07:
おっとスペーサーじゃないです。スタビライザーです…直しておきます。

kushima8, 2021-01-07:
まずは、Gitに置いてあるdxfファイルがインチ出力していたものであり、
こちらの意図したファイルと異なっておりました。
業者に依頼する際も同じファイルを使用していたのですが、
問題なく納品されておりましたので今まで気づきませんでした。
お手数おかけしました。
現在はすべてmm出力のものと差し替えております。

トッププレートのスタビライザー穴の形状ですが、
こちらのものを参考に作成しております。
https://www.mouser.com/datasheet/2/71/mx_cat-1159901.pdf

こちらのデータシートですとbに該当する長さが14mm+6.65mm=30.45mmです。
2Uサイズのスタビライザーの大きさが30mmと聞いていましたので、
こちらの寸法から少しだけ大きくし、30.55mm前後になるように設計いたしました。

現在アルミトッププレートを装着し、同じスタビライザーを使用しているものがあるのですが、
問題なく装着でき可動しております。
しかし、設計がギリギリであるためプレートとスタビライザーの隙間がほぼない状態であります。

今回装着するにあたって、0.1～0.2mmほど削り広げたとのことですが、
穴の設計に余裕がなく、スタビライザーの個体差を許容できず装着できなかったものではないかと思われます。

koron, 2021-01-08:
ありがとうございます。
ほんの少し削れば済む程度でしたので影響としては軽微というか
無いも同然です。

ただ1点だけキットに付属のアクリルトッププレートで
スタビライザーおよびキースイッチ用の穴寸法がDXFにくらべ約0.2mm大きい
ことだけが気にかかっています。
これはアクリルの加工方法に由来する誤差なのか
それとも何かしらの修正データによるものなのか
そこだけ心当たりがありましたら教えていただけると幸いです。

koron, 2021-01-08:
更新後のDXFは後程チェックさせていただきます。

kushima8, 2021-01-08:
加工を依頼した業者が使用しているレーザー幅が約0.2mmであり、
加工上線の両端約0.1mmが余分に削られている為、
DXFで指定した数値と実寸に誤差が発生しております。

koron, 2021-01-08:
あーなるほど!完璧にスッキリしました。ありがとうございます。

koron, 2021-01-08:
最後に判明した事実をまとめて本issueは閉じます。

* 游舎工房で販売しているスタビライザー足の幅 `a` はCherry MXの出している寸法と公差を超えて大きかった
    参考: 6.8mm > 0.262±0.004in (6.65±0.10mm)
* Re64のトッププレートは設計上 6.75mm なので公式の `a` を挿入するのに十分である
* Re64のキットに含まれるアクリル製トッププレートは加工業者のレーザー幅のため 0.1mm ずつ多く削られる
    `a` は理論値で 6.95mm 実測値 7.0mm であり「件のスタビライザー」を挿入できている

Closed 2021-01-08.

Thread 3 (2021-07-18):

Re40:ファームウエアの書き込みで上手くできません

corelax-dev, 2021-07-18:
以下サイトの手順で、「Auto-flash enabled」と出てこないです。キーボードのリセットボタンを押下してもメッセージが出ないのですが何が原因かご教示いただけますでしょうか。

https://salicylic-acid3.hatenablog.com/entry/qmk-toolbox
-QMK Toolboxを使用する場合（旧説明内容）
 -Auto-Flashをオンにする
  -下図赤◯のチェックボックスをオンにし、下の黒い画面に「Auto-flash enabled」と出てくるのを確認する。

kushima8, 2021-09-06:
申し訳ありませんがその情報だけですと原因が特定出来ません。
ProMicroのみの状態で書き込みが出来るか、など原因の切り分けを行ってから相談してください。

Closed 2021-10-05.

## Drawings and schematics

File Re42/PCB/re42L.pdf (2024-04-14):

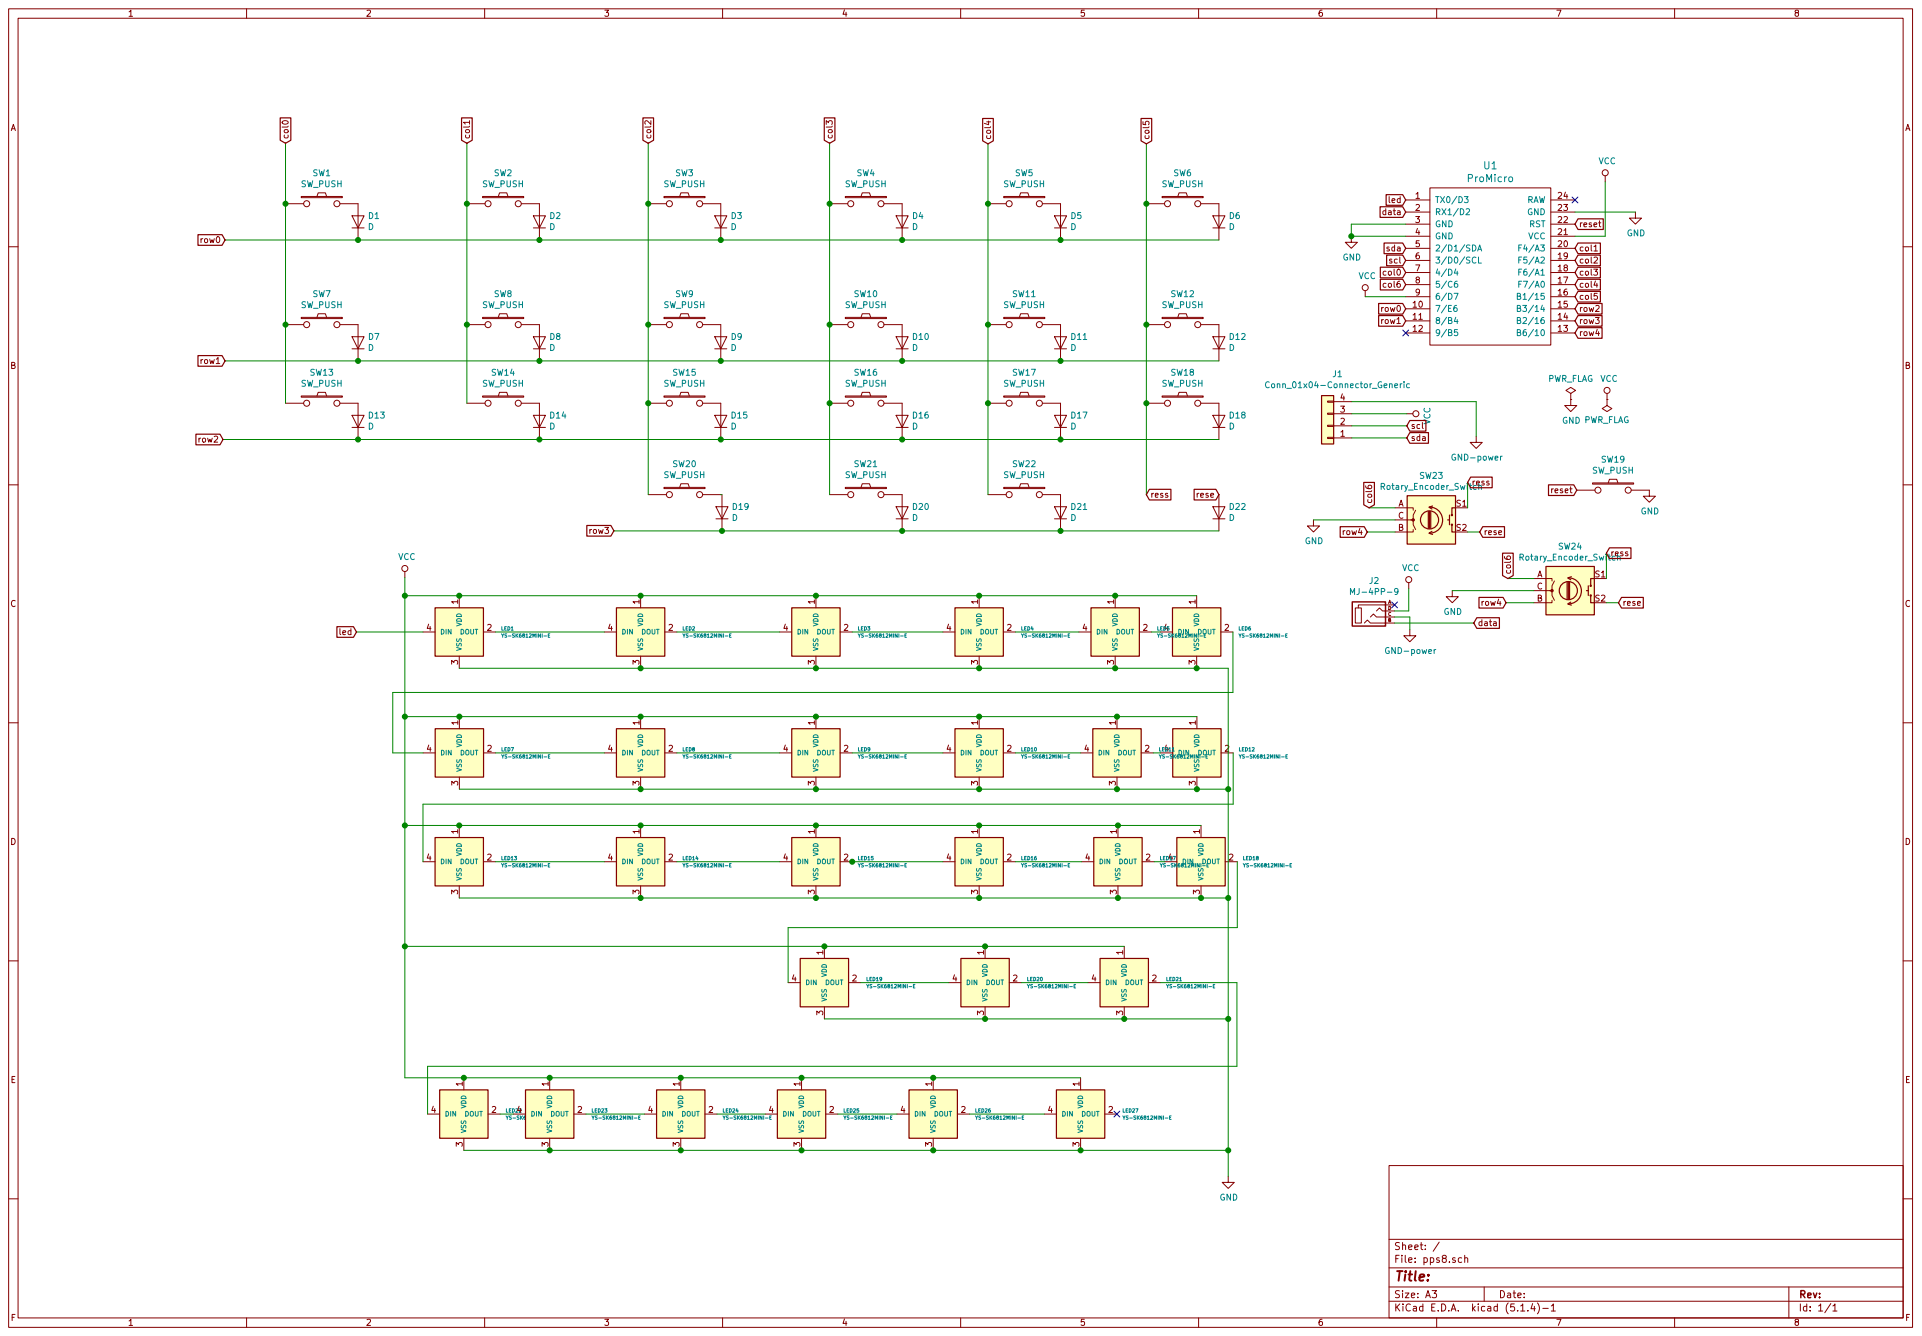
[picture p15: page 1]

1 DOUT 2 VSS 3 DIN 4 LED9 YS-SK6812MINI-E GND PWR_FLAG

1 DOUT 2 VSS 3 DIN 4 LED7 YS-SK6812MINI-E SW19 SW_PUSH GND

1 DOUT 2 VSS 3 DIN 4 LED4 YS-SK6812MINI-E D21 D VDD

1 DOUT 2 VSS 3 DIN 4 LED10 YS-SK6812MINI-E D20 D

1 DOUT 2 VSS 3 DIN 4 LED1 YS-SK6812MINI-E VDD

1 DOUT 2 VSS 3 DIN 4 LED2 YS-SK6812MINI-E VDD

1 DOUT 2 VSS 3 DIN 4 LED3 YS-SK6812MINI-E VDD

1 DOUT 2 VSS 3 DIN 4 LED5 YS-SK6812MINI-E VDD

1 DOUT 2 VSS 3 DIN 4 LED6 YS-SK6812MINI-E VDD

1 DOUT 2 VSS 3 DIN 4 LED8 YS-SK6812MINI-E VDD

1 DOUT 2 VSS 3 DIN 4 LED11 YS-SK6812MINI-E VDD

1 DOUT 2 VSS 3 DIN 4 LED12 YS-SK6812MINI-E VDD

1 DOUT 2 VSS 3 DIN 4 LED17 YS-SK6812MINI-E VDD

1 DOUT 2 VSS 3 DIN 4 LED20 YS-SK6812MINI-E VDD

1 DOUT 2 VSS 3 DIN 4 LED13 YS-SK6812MINI-E

1 DOUT 2 VSS 3 DIN 4 LED18 YS-SK6812MINI-E VDD

1 DOUT 2 VSS 3 DIN 4 LED14 YS-SK6812MINI-E VDD

1 DOUT 2 VSS 3 DIN 4 LED15 YS-SK6812MINI-E VDD

1 DOUT 2 VSS 3 DIN 4 LED16 YS-SK6812MINI-E VDD

1 DOUT 2 VSS 3 DIN 4 LED19 YS-SK6812MINI-E

1 DOUT 2 VSS 3 DIN 4 LED21 YS-SK6812MINI-E

1 DOUT 2 VSS 3 DIN 4 LED24 YS-SK6812MINI-E VDD

File: pps8.sch Sheet: / VDD

1 DOUT 2 VSS 3 DIN 4 LED22 YS-SK6812MINI-E

1 DOUT 2 VSS 3 DIN 4 LED23 YS-SK6812MINI-E

1 DOUT 2 VSS 3 DIN 4 LED27 YS-SK6812MINI-E VDD

1 DOUT 2 VSS 3 DIN 4 LED25 YS-SK6812MINI-E VDD

1 DOUT 2 VSS 3 DIN 4 LED26 YS-SK6812MINI-E VDD

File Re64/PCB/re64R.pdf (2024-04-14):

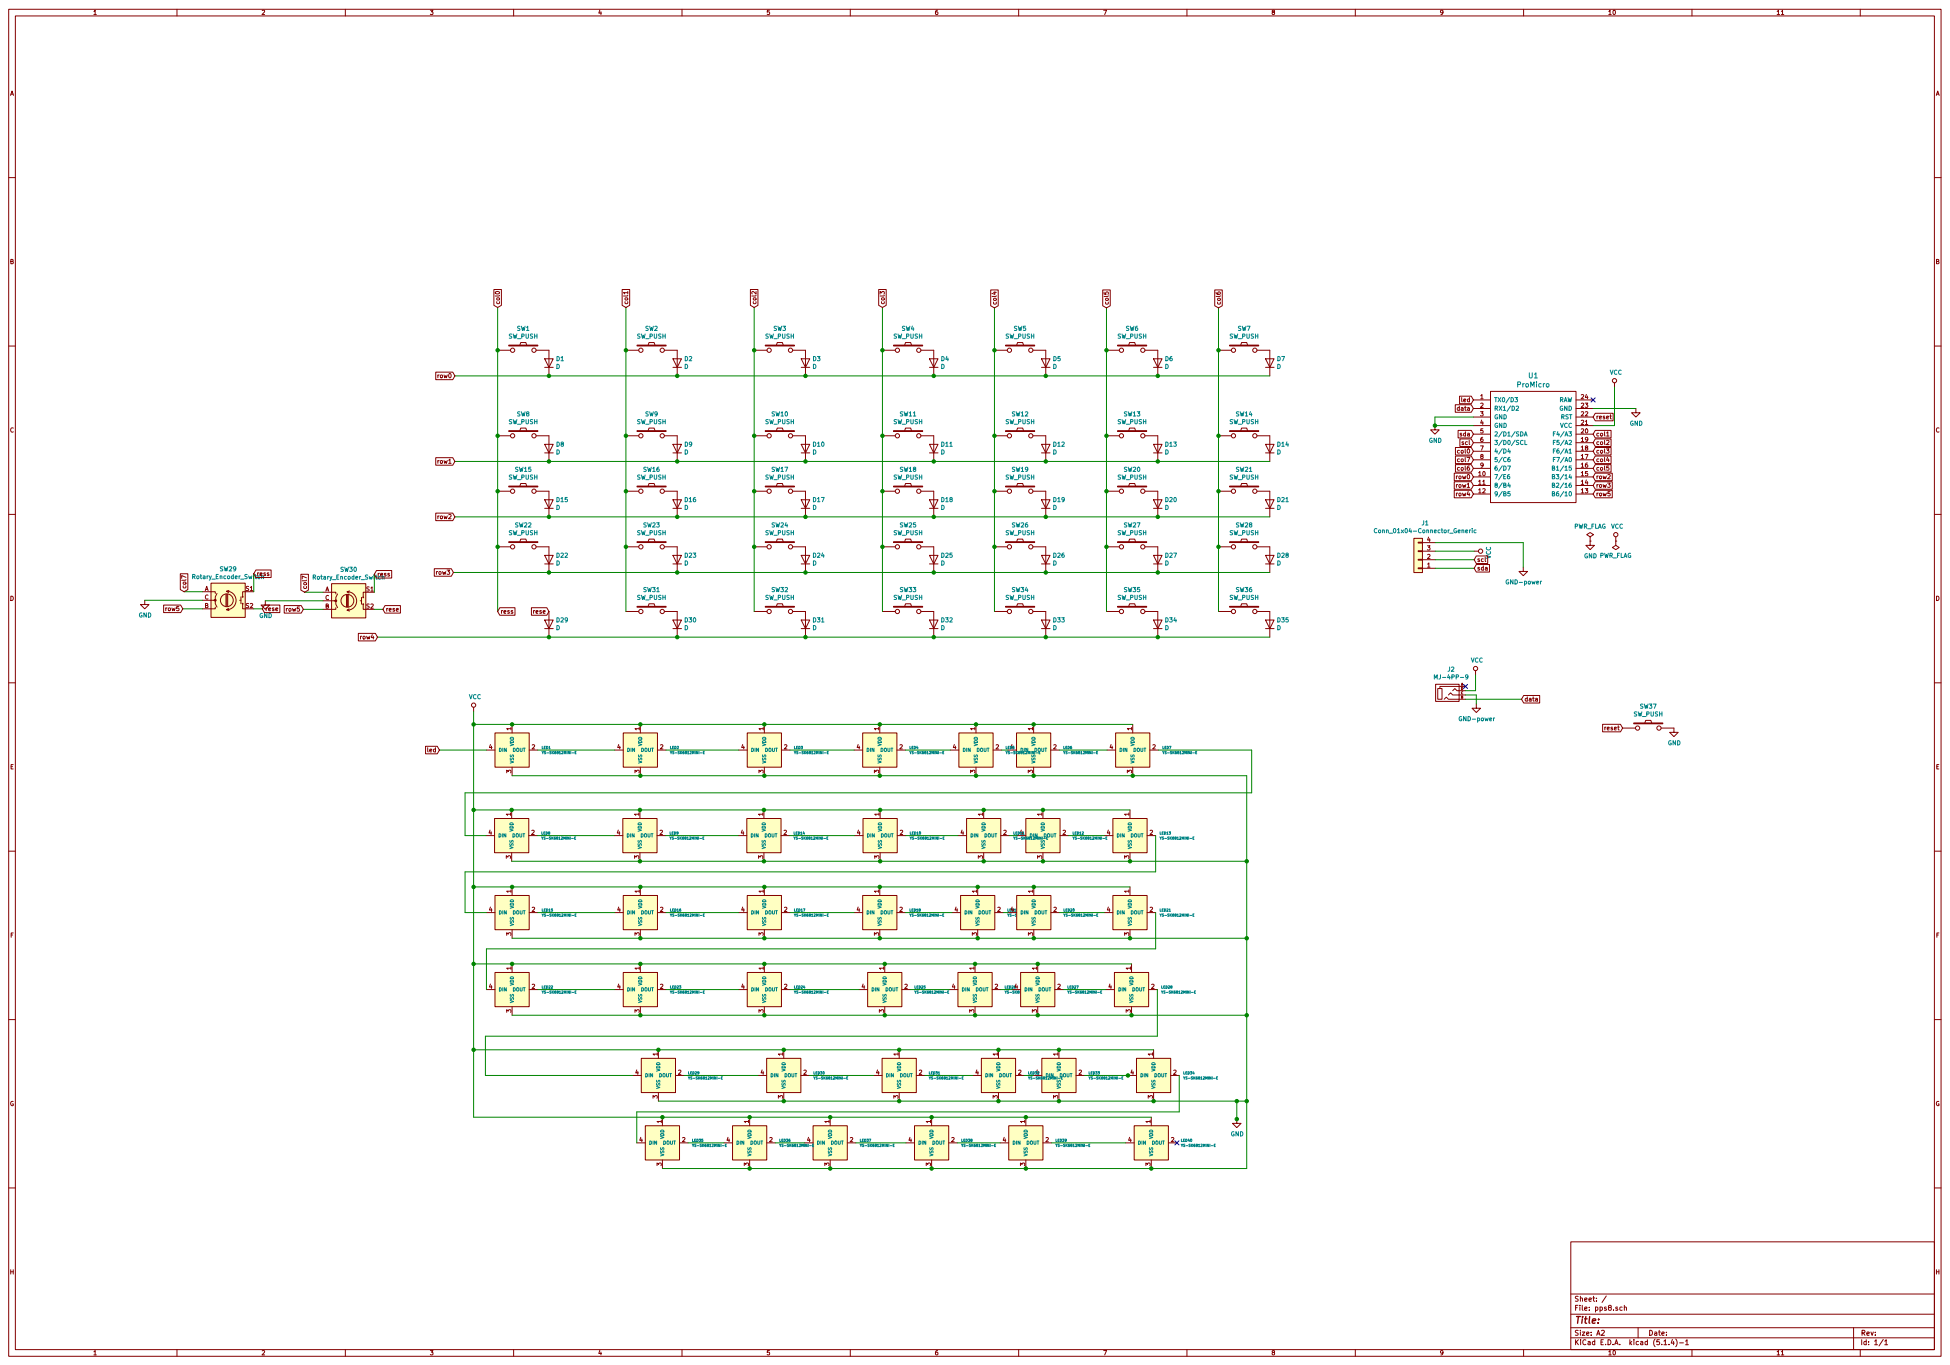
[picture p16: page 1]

1 DOUT 2 VSS 3 DIN 4 LED5 YS-SK6812MINI-E GND

1 DOUT 2 VSS 3 DIN 4 LED8 YS-SK6812MINI-E D31 D

1 DOUT 2 VSS 3 DIN 4 LED1 YS-SK6812MINI-E

1 DOUT 2 VSS 3 DIN 4 LED6 YS-SK6812MINI-E VDD

1 DOUT 2 VSS 3 DIN 4 LED2 YS-SK6812MINI-E VDD

1 DOUT 2 VSS 3 DIN 4 LED7 YS-SK6812MINI-E VDD

1 DOUT 2 VSS 3 DIN 4 LED3 YS-SK6812MINI-E VDD

1 DOUT 2 VSS 3 DIN 4 LED4 YS-SK6812MINI-E VDD

1 DOUT 2 VSS 3 DIN 4 LED9 YS-SK6812MINI-E VDD

1 DOUT 2 VSS 3 DIN 4 LED14 YS-SK6812MINI-E VDD

1 DOUT 2 VSS 3 DIN 4 LED17 YS-SK6812MINI-E VDD

1 DOUT 2 VSS 3 DIN 4 LED10 YS-SK6812MINI-E VDD

1 DOUT 2 VSS 3 DIN 4 LED21 YS-SK6812MINI-E VDD

1 DOUT 2 VSS 3 DIN 4 LED13 YS-SK6812MINI-E VDD

1 DOUT 2 VSS 3 DIN 4 LED12 YS-SK6812MINI-E VDD

1 DOUT 2 VSS 3 DIN 4 LED11 YS-SK6812MINI-E VDD

1 DOUT 2 VSS 3 DIN 4 LED39 YS-SK6812MINI-E VDD

1 DOUT 2 VSS 3 DIN 4 LED15 YS-SK6812MINI-E VDD

1 DOUT 2 VSS 3 DIN 4 LED16 YS-SK6812MINI-E VDD

1 DOUT 2 VSS 3 DIN 4 LED18 YS-SK6812MINI-E

1 DOUT 2 VSS 3 DIN 4 LED19 YS-SK6812MINI-E

1 DOUT 2 VSS 3 DIN 4 LED20 YS-SK6812MINI-E

1 DOUT 2 VSS 3 DIN 4 LED22 YS-SK6812MINI-E VDD

1 DOUT 2 VSS 3 DIN 4 LED23 YS-SK6812MINI-E VDD

1 DOUT 2 VSS 3 DIN 4 LED24 YS-SK6812MINI-E

1 DOUT 2 VSS 3 DIN 4 LED28 YS-SK6812MINI-E VDD

1 DOUT 2 VSS 3 DIN 4 LED25 YS-SK6812MINI-E

1 DOUT 2 VSS 3 DIN 4 LED26 YS-SK6812MINI-E VDD

1 DOUT 2 VSS 3 DIN 4 LED27 YS-SK6812MINI-E

1 DOUT 2 VSS 3 DIN 4 LED29 YS-SK6812MINI-E

1 DOUT 2 VSS 3 DIN 4 LED31 YS-SK6812MINI-E VDD

1 DOUT 2 VSS 3 DIN 4 LED30 YS-SK6812MINI-E
GND VDD

1 DOUT 2 VSS 3 DIN 4 LED32 YS-SK6812MINI-E VDD

1 DOUT 2 VSS 3 DIN 4 LED33 YS-SK6812MINI-E

1 DOUT 2 VSS 3 DIN 4 LED34 YS-SK6812MINI-E VDD

1 DOUT 2 VSS 3 DIN 4 LED35 YS-SK6812MINI-E

1 DOUT 2 VSS 3 DIN 4 LED36 YS-SK6812MINI-E VDD

1 DOUT 2 VSS 3 DIN 4 LED37 YS-SK6812MINI-E VDD

1 DOUT 2 VSS 3 DIN 4 LED38 YS-SK6812MINI-E

1 DOUT 2 VSS 3 DIN 4 LED40 YS-SK6812MINI-E

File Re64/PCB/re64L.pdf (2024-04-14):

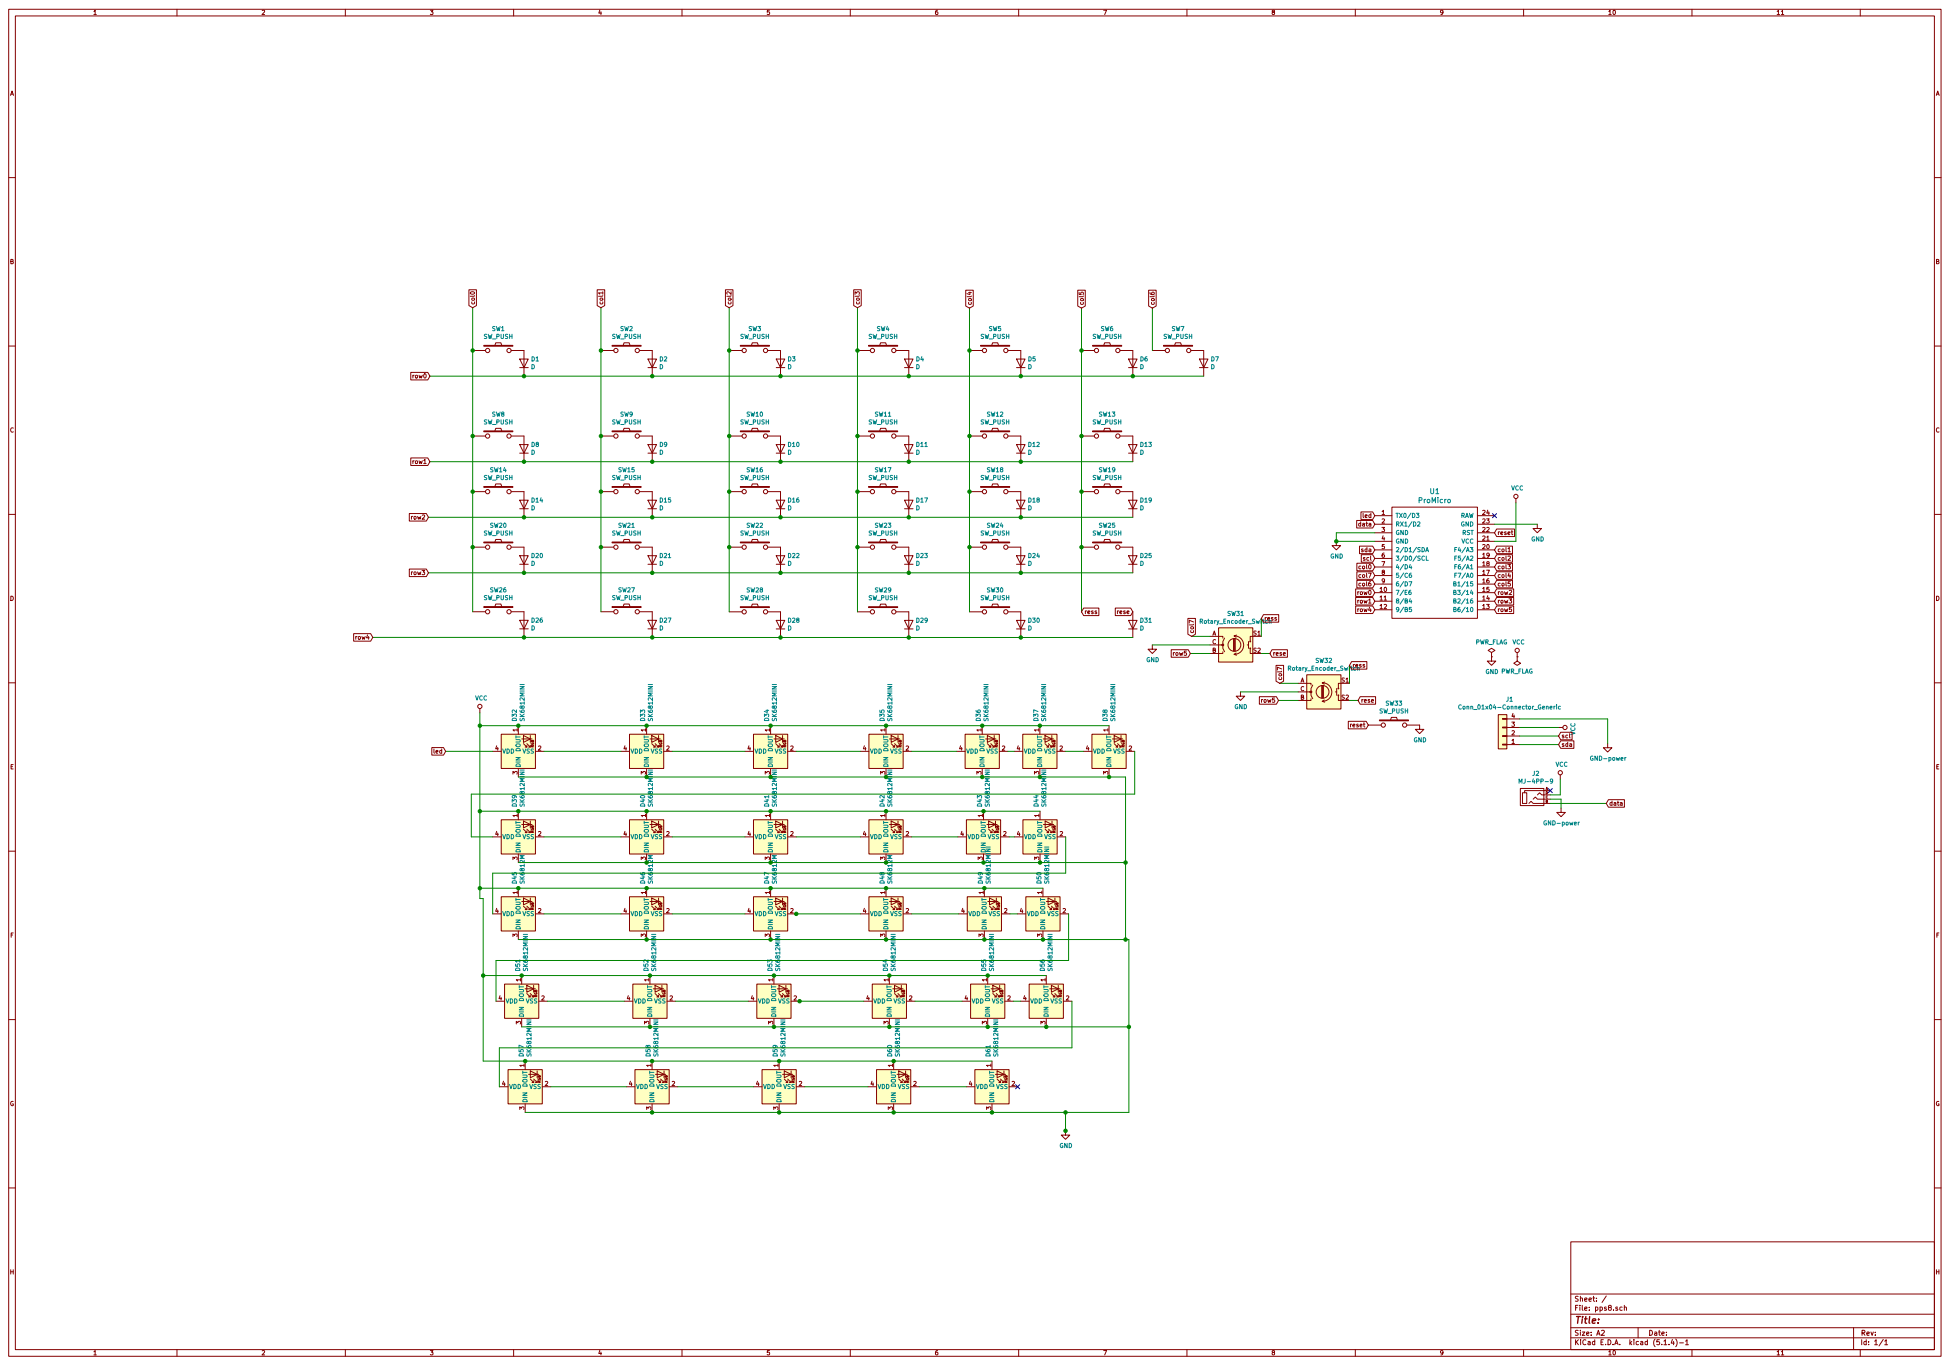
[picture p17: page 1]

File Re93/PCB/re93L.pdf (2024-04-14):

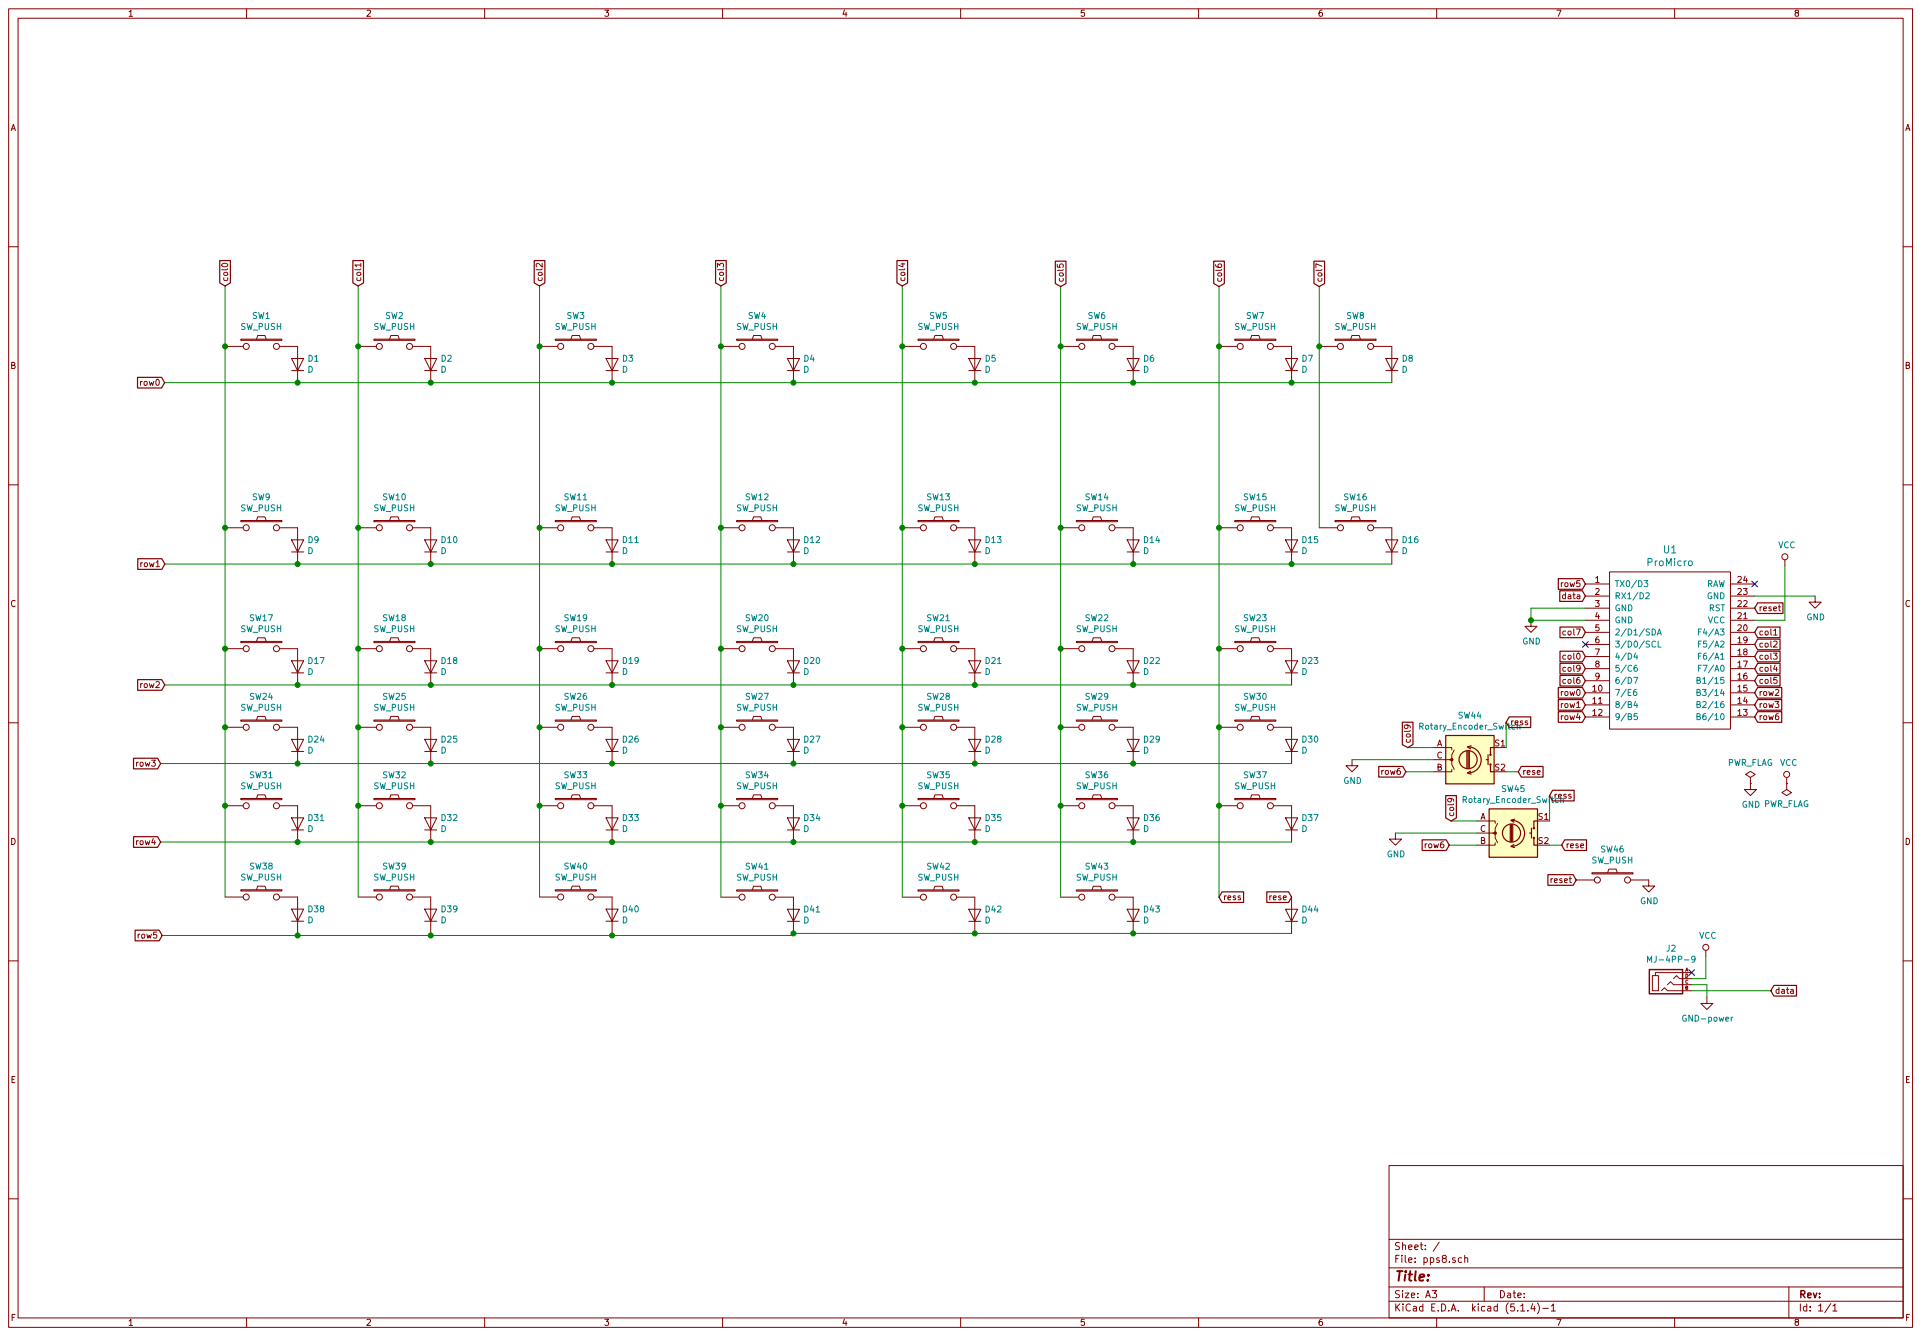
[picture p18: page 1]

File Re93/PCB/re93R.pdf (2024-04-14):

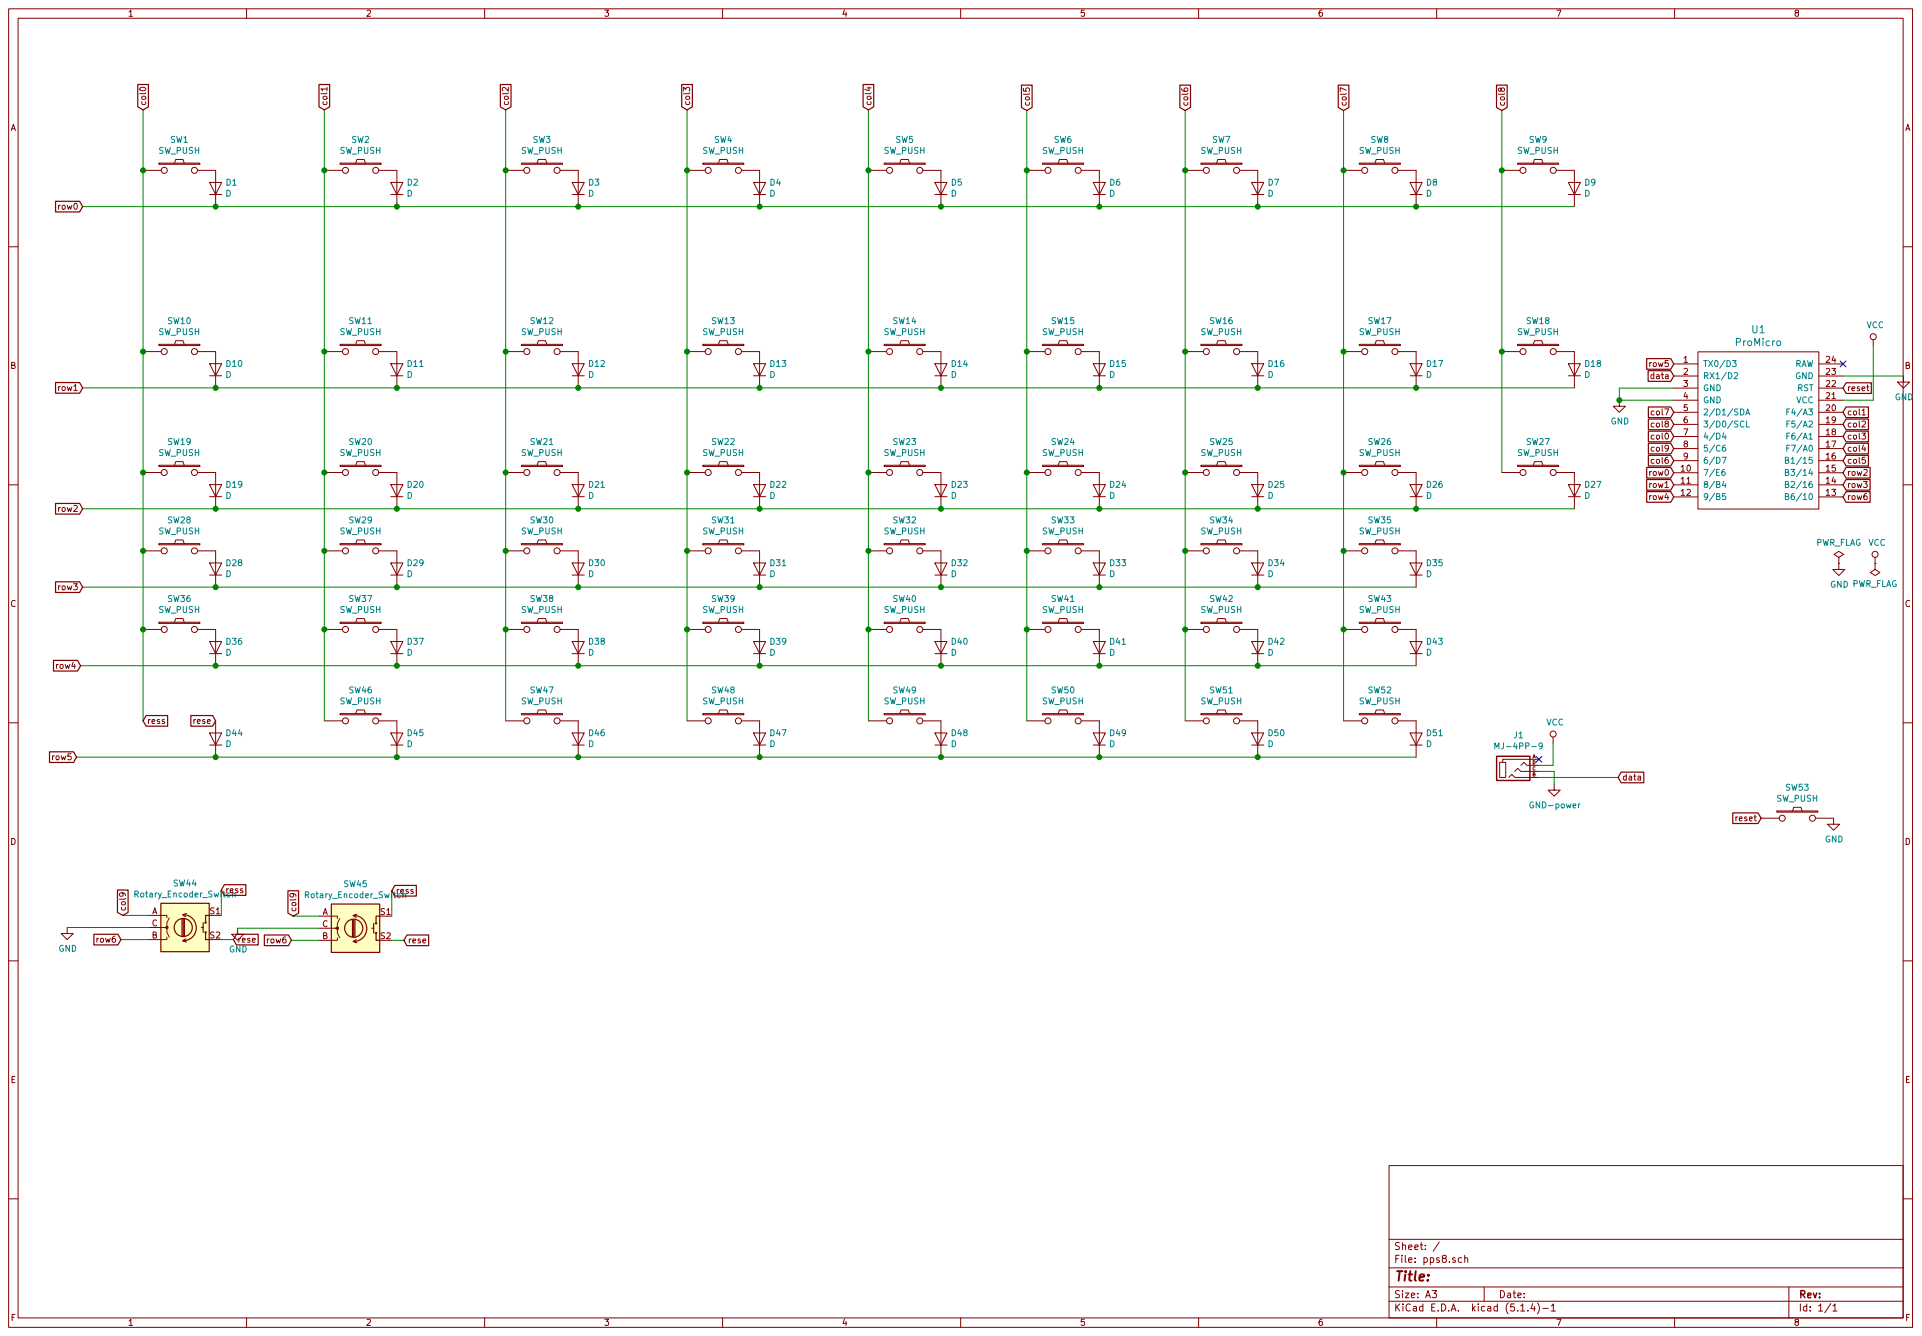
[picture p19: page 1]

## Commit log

2020-08-01 Add Re40/Re64 buildguide etc
    [Re40_acrylic.dxf, Re40_bottm.dxf, Re40_top.dxf]
2020-10-25 Update re42
    [re42_bottm.dxf, re42_protective.dxf.dxf]
2021-01-07 Update Plate
    [re40_bottom.dxf, re40_protective.dxf, re42_bottom.dxf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]
2024-04-14 ADD PCB
    [re42.kicad_pcb, re64v2.kicad_pcb, re93.kicad_pcb]
